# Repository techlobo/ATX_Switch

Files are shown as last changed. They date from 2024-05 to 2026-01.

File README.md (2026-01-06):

# ATX Switch

## Control ATX capability of multiple systems from PiKVM host

An extension unit to a [PiKVM](https://github.com/pikvm/pikvm) based controller that enables the WebUI based ATX controls (PWR button; Reset button; HDD LED and PWR LED) to be switched between the physical ATX headers, and their associated case controls, on different PC / Server motherboards.

Supports the control of multiple ATX-enabled endpoint devices, in conjunction with a KVM switch, from a single PiKVM unit.

>[!NOTE]
>An interface adaptor has now been produced that enables PiKVM v3 and v4 Plus devices to be connected to, and manage, an ATX Switch environment

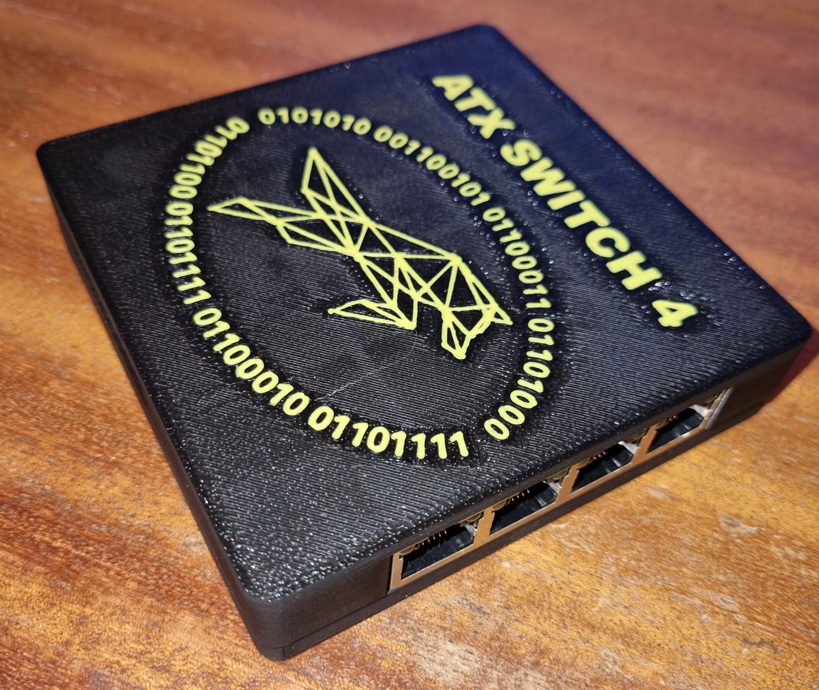
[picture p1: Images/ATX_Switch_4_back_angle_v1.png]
ATX Switch 4 picture
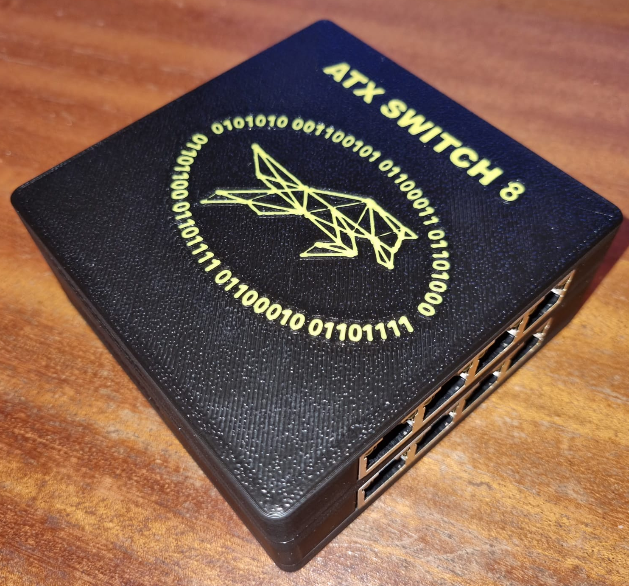
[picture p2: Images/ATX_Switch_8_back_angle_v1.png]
ATX Switch 8 picture
|  |  |
| --- | --- |

## Features

- $\color{green}{\textsf{Low cost}}$ / **<u>self-assembly</u>**

- 4-port and 8-port units can be built
  - [Board / case designs available](https://github.com/techlobo/ATX_Switch/tree/main/ATX_Switches)
  
- I2C addressable (user selectable between 0x20 – 0x27)

- Daisy chainable (theoretically up to 8 units / 64 ports)

- Fully isolated

- Compatible with PiKVM assigned ATX GPIO pins

- Port selection controls available in WebUI (configurable via override.yaml)

- ATX operations use standard PiKVM WebUI interface

- Potential for ATX operations to be performed via I2C rather than GPIO (**not implemented yet**)

- Compatible with existing PiKVM based ATX adapter boards that are installed inside managed PC / workstation / server
  - Design available to build own [affordable ATX adapter board](https://github.com/techlobo/ATX_Switch/tree/main/ATX_Adapter_board)
  
- ATX Switch input port not compatible with existing v3 / v4 PiKVM hardware designs of ATX port due to requirement for providing control and power lines. Therefore cannot directly connect commercial PiKVM unit to ATX Switch. Two build approaches available:
  - [Low-cost DIY design](https://github.com/techlobo/ATX_Switch/tree/main/DIY_PiKVM) available based on v3 Box build (**self-assembly**)
  
    - 👀 Limited to 1080P @50Hz 👀
  
      <p align="center">
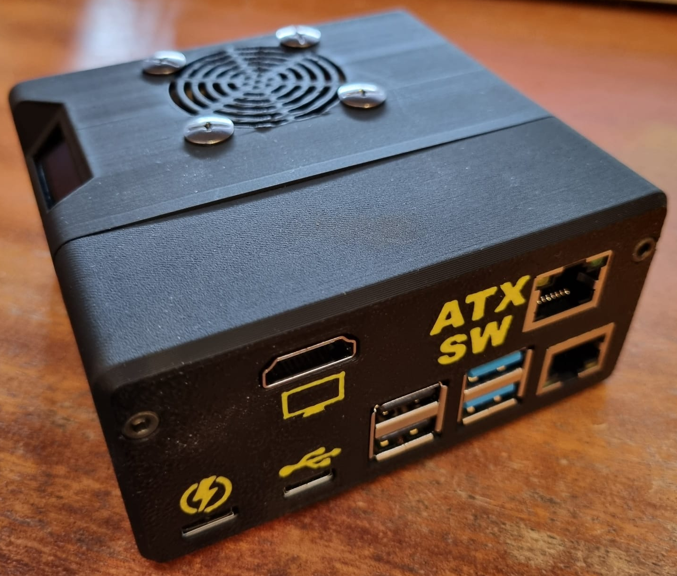
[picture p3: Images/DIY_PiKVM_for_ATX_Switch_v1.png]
DIY PiKVM for ATX Switch operation
      
      </p>

  - $\color{green}{\textsf{New addition}}$ - [ATX Switch Interface adaptor](./ATX_Switch_Interface_adaptor/README.md) (**self assembly**) enables connection between v2 / v3 / v4+ devices and ATX Switch environment.
  
    <p align="center">
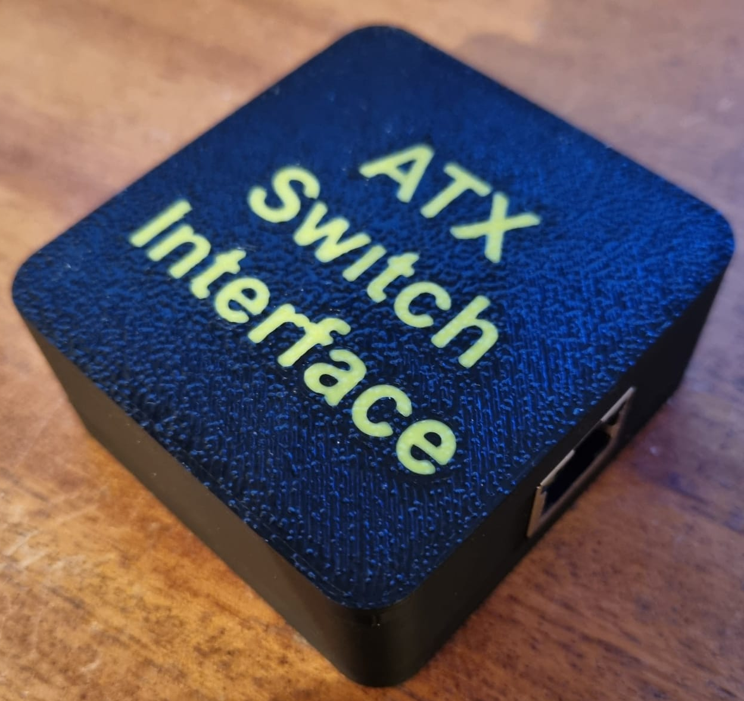
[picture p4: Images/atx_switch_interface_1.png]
ATX Switch Interface adaptor
    
    </p>
  
  - $\color{green}{\textsf{Further addition}}$ - [Low cost DIY v2 Design](./DIY_PiKVM_v2/README.md) (**self assembly**) - modified version of DIY design above to provide standard ATX functionality as per v3 / v4 PiKVM units
  
    <p align="center">
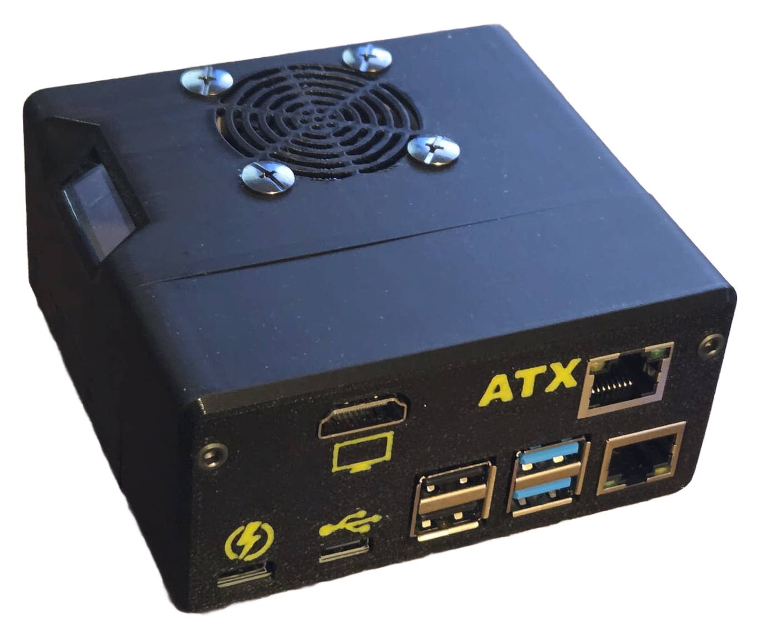
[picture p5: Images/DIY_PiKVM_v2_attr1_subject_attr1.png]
DIY PiKVM for standard ATX operation
    
    </p>

## Typical deployments

##### $\color{purple}{\textsf{DIY PiKVM - most cost effective for home lab environments}}$

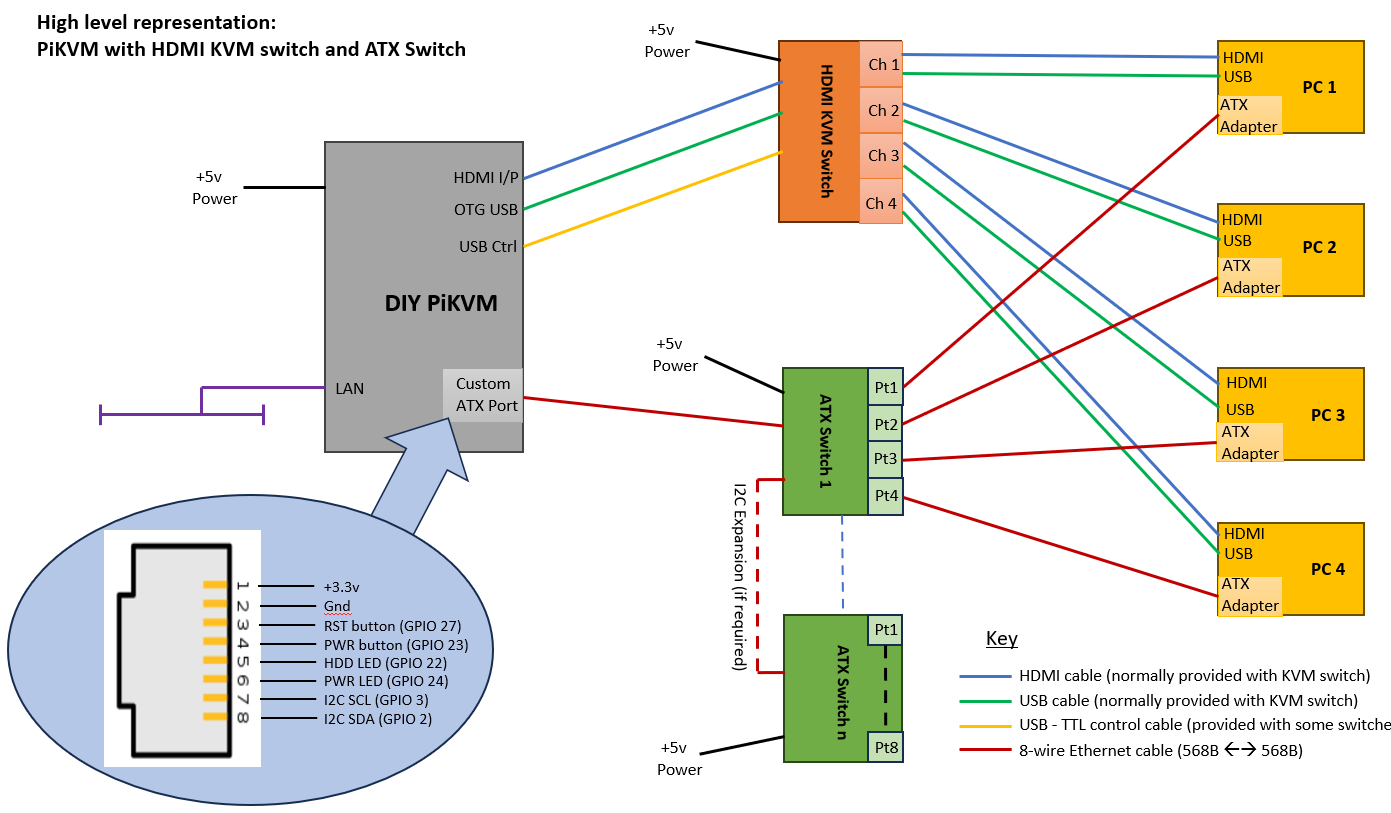
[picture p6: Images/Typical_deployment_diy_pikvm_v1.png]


##### $\color{purple}{\textsf{Commercial PiKVM environments}}$

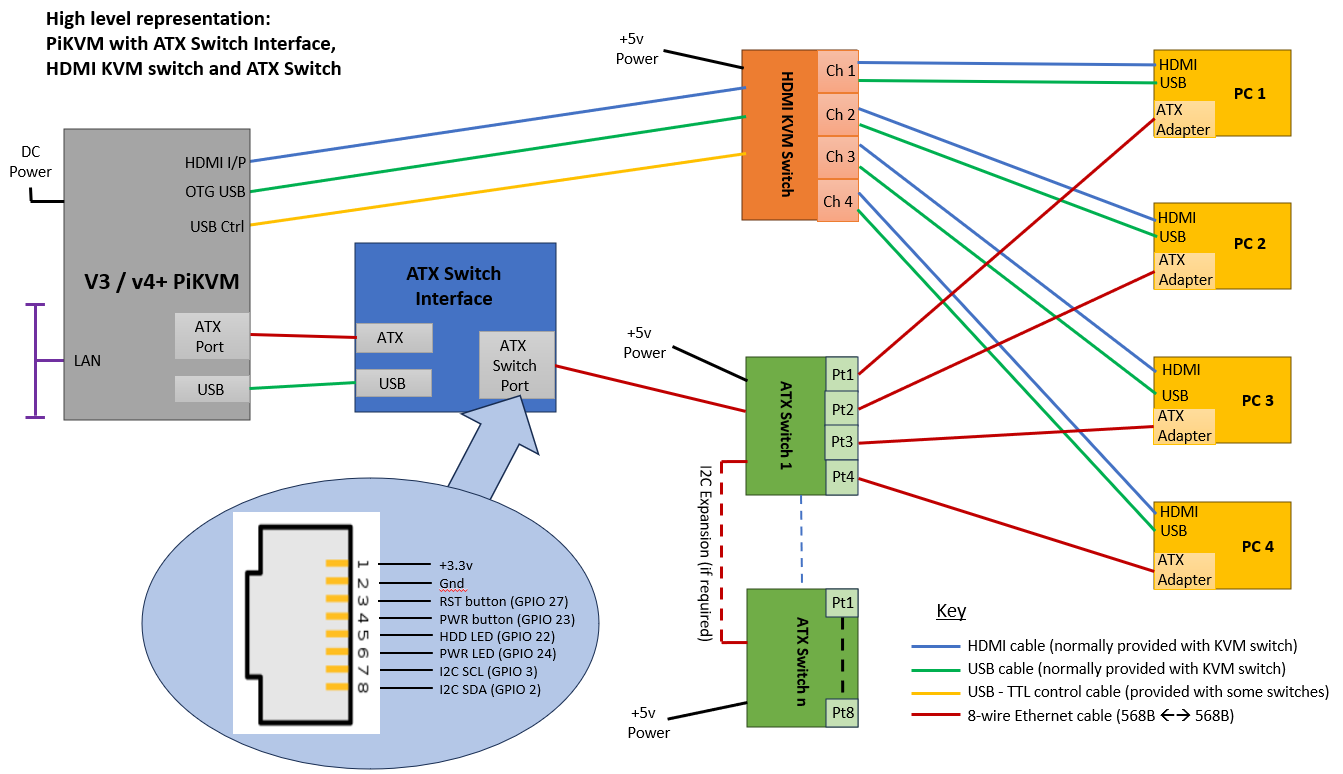
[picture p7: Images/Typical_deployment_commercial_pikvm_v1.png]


## Background

As PiKVM usage was developing, more users were wanting to extend its functionality to support multiple end-devices from a single PiKVM controller. This led to experimentation regarding the use of HDMI KVM switches to enable multiplexing of input / output streams between the devices.

This work by the community has led to a greater understanding of which HDMI KVM switches work best with PiKVM, and how to configure them. Some of this information has been [documented](https://docs.pikvm.org/multiport/) on the PiKVM site, whilst other information is available in the PiKVM discord server and various articles online.

However these approaches did not address one of the key capabilities of the PiKVM when used in a multi-device scenario - the ability to switch on / off the remote device, and to a lesser extent a visual confirmation of its power and HDD status.

I had just restarted an interest in hobby electronics and wanted an affordable solution for managing my home server environment,  so decided that this would be a good first project. 

I originally considered the construction of discrete '*intelligent*' controllers, using ESP32 (or similar) MCU's connected to the PiKVM via a bus based approach (e.g. Modbus, CANbus, MQTT). It was interesting testing these approaches out whilst determining how to: **design / build them** (e.g. component selection, PCB design, enclosure design); **deploy them** (e.g. where / how to install them, how to power them, how to communicate with them); and **manage them** (e.g. configuration / debug / maintenance). 

I learnt a lot during this exercise, but finally concluded that the approaches I was considering were more complicated than necessary, and that a simpler / more robust / cheaper solution could be produced just using devices based on discrete components connected directly to the PiKVM controller - hence the ATX Switches!

## Operation

When correctly configured, operation of the ATX Switch(es) is undertaken within the PiKVM WebUI. The means of this operation depends on how the system has been set up (see installation instructions).

### Managed device selection

This is performed within the **Source** menu option by either:

- activating the associated ATX(x) button, OR
- activating the associated Input(x) button if HDMI KVM switch integration has been performed. 

The selected port on the ATX Switch being indicated on the associated menu LED.

<p align="center">
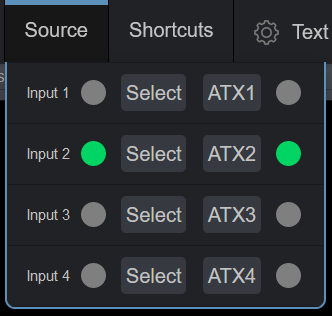
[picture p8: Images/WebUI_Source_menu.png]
DIY PiKVM 3D printed case

</p>

The video below gives a brief demonstration of the above activations, initially by using the ATXn selector buttons to switch between the managed devices - the associated LED (within the Source menu) changing to confirm selection complete. You can also see that the ATX menu LED icons change to indicate the status of the selected device (with ATX1 being powered off). The second part of the video shows selection of the target device using the Source menu 'Select' buttons which are mapped to the attached HDMI KVM switch. Observe how the selection of the KVM target causes the ATX Switch to be moved to the associated ATX interface.

<video src="./Images/PiKVM_ATX_op1.mp4"></video>

https://github.com/techlobo/ATX_Switch/assets/95144096/9a94704d-ef98-44f7-9990-24d5c0a44960

### ATX Functionality (via GPIO)

This is performed via the ATX menu in the WebUI, with the Power LED and HDD LED status for the selected device being indicated in the menu bar (*Note - this is all standard PiKVM functionality when GPIO controls are being used*).

The video below again shows the target device being selected from the Source Select buttons, but in this case the target device (4) is powered down. The completion of the LED representations in the Source menu shows that the 4th HDMI KVM port was selected alongside the ATX Switch 4th port. It can also be seen from the ATX menu that the status indications for Power and HDD are blank. On using the standard PiKVM ATX functionality to power on the target device it can be seen that the activity indicators start to operate, and the boot process is observed.

<video src="./Images/PiKVM_ATX_op2.mp4"></video>

https://github.com/techlobo/ATX_Switch/assets/95144096/6d380cd4-e1c7-4d97-97c2-12fe709a398f

The presentation of the Source menu is down to personal preference (as defined in the override.yaml file). It is not necessary to provide the ATX selection buttons, or indeed the selected ATX LEDs, if you are happy with just using one set of selection buttons, and having one set of 'selected' LEDs. Personally I prefer to show both sets of LEDs.

## Rough Costs

My approximate material costs for the final pieces of this project (not including IC sockets) were as shown below, on a pro-rata basis:

| Item | Rough cost - own case (£) | Rough cost - buy case (£) |
| --- | :---: | :---: |
| ATX Adapter board | $\color{green}{\textsf{3.00}}$  | N/A |
| ATX Switch 4 | $\color{green}{\textsf{19.00}}$ | 39.00 |
| ATX Switch 8 | $\color{green}{\textsf{27.00}}$ | 51.00 |
| DIY PiKVM (ATX-SW) | $\color{green}{\textsf{97.70}}$ | 119.70 |
| ATX Switch Interface | $\color{green}{\textsf{7.50}}$  | 26.00 |
| DIY PiKVM v2 (ATX only) | $\color{green}{\textsf{98.20}}$ | 118.20 |

>[!NOTE]
>The costs are based on the use of optocouplers for the ATX Switches. If SSRs were to be used then add at least an additional £10 to the cost of a 4-port, and £20 to an 8-port device.
>
>In the case of the DIY PiKVM v2 this has been costed using the KAQY214 SSR's to more closely match standard PiKVM spec.

A bit more detail is provided [here](./Rough_costs/README.md).

Some further savings can be made (e.g. cheaper fan, no fan at all, use of dupont cable rather than motherboard switch extender,....) but these are what I went with.

## Credits

None of the above would work without the amazing efforts of the developers of [PiKVM](https://pikvm.org/), and their support of the [Open Source community](https://github.com/pikvm). Hats off to them!

## Summary & Disclaimer

This is a synopsis of my adventures in this area while setting up management on my home lab environment. It works for me, but there are no guarantees it will for you. I've documented this primarily for my own benefit, including getting some idea of how Github and Markdown works. However, if you want to try something similar then please feel free to use any (*or none*) of the above material - $\color{red}{\textsf{at your own risk...!}}$

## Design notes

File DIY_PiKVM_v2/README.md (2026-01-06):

# DIY PiKVM v2 (single ATX) Section

<p align="center">
DIY PiKVM v2 3D printed case
</p>

The *DIY PiKVM v2* consists of:

## Hardware

- [3D printed case](./Case/README.md)
- Pi4 (suitable for PiKVM)
- [Power splitter](https://www.tindie.com/products/8086net/usb-cpwr-splitter/) from 8086.com
  - Barrel jack version not required, although will fit.

- [Angled USB-C cable](https://www.startech.com/en-gb/cables/r2ccr-15c-usb-cable) connecting Power splitter to Pi4 USC-C power supply port
  - Other cables / adaptors can potentially be used but I found this item to be best for the available space / bend.

- [C790](https://geekworm.com/products/c790) to provide HDMI-CSI2 video capture 
  - FPC 15-pin cable should also be supplied 
  - (audio if required using supplied I2S cable)

- [ATX connector](./ATX_connector_board_for_Pi/README.md) (RJ45 configured as per standard PiKVM ATX socket)
- [0.91 inch OLED screen](https://www.aliexpress.com/item/1005005281308478.html) (typically white / yellow / blue)
  - 4-pin female-to-female dupont ribbon cable

- 4x 2mm silicone cushion mat self adhesive rubber feet
- **Optional** - 40x40x10 fan (preferably PWM). Few types tested:
  - [Noctua NF-A4x10 5V PWM](https://noctua.at/en/nf-a4x10-pwm)
  - [Pi5 PWM fan](https://thepihut.com/products/4010-cooler-black-fan-for-raspberry-pi-5?variant=42684803907779)
  - [GeeekPi PWM fan](https://www.amazon.co.uk/GeeekPi-Raspberry-Adjustable-40x40x10mm-Radiator/dp/B092ZF995F?th=1)
  - There are others, but not tested.

The case construction allows for mainly tool-less assembly, however the following bolts / connectors **are** used in the build of the unit:

- 2x M3 35mm bolts for connecting the front and back of the case together.
  - I used [black hex socket head bolts](https://www.aliexpress.com/item/1005005832717344.html) (to match in with the black PLA) together with [M3(OD4.5) 6mm heat inserts](https://www.aliexpress.com/item/1005006042691803.html) in the case back to provide a good fit that can be opened / closed easily. The use of heat inserts is not compulsory but the inner diameter of the mounting hole on the back case will probably need to be adjusted if M3 screws (or bolts) are to be used on their own.
- 4x M3 15mm bolts / nuts to fasten the fan into place
  - I used [black D4(M3) screw book binding post screws](https://www.aliexpress.com/item/32789781458.html) together with rubber washers to provide a good looking finish with the Noctua NF-A4x10 5V PWM fan.
- **Optional** - depending on preference, an M2.5 brass standoff spacer (18mm) can be used in conjunction with 2x M2.5 6mm low flat screws to fasten the ATX Switch connector board to the Raspberry Pi4. This is not essential as the case construction will hold the components together, but may provide rigidity during assembly.

Hardware assembly and software is basically the same as for [DIY_PiKVM](../DIY_PiKVM/README.md), although the ATX Switch scripts are not required if only using this as a 1:1 v2 ipKVM device. The ATX Switch scripts do need to be installed if intending to use this device in conjunction with the [ATX Switch Interface adaptor](../ATX_Switch_Interface_adaptor/README.md) (see relevant installation notes).

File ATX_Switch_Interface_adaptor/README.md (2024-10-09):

# ATX Switch Interface

## Design Criteria

After producing the ATX Switch / DIY PiKVM combination for my home environment, I revisited whether it would be possible to use the ATX Switch with one of the standard PiKVM's.

The main interface to the ATX Switch environment is the relevant GPIO pins, and I2C. However the PiKVM devices were fixed units - with no expansion capability unless you used existing ports, or 'hacked' the units (which most people won't want to do!).

Therefore it was necessary to determine if the provided ports could be utilised / re-purposed.

The standard ATX port on the PiKVM has a fixed pinout, but the relevant GPIO pins could be mapped externally to the configuration used by the ATX Switch.

Which left the need to provide an I2C interface.

The only other ports available for use on the PiKVM were the USB ports, so it was decided to look at providing a USB<-->I2C interface.

A number of USB<-->I2C adaptors were reviewed based on functionality / availability / support / cost .....

It was determined that the CP2112 HID USB to SMBus / I2C Bridge had kernel support within Arch Linux[^1], and was available in a relatively inexpensive 'debug board' package:

 <p align="center">
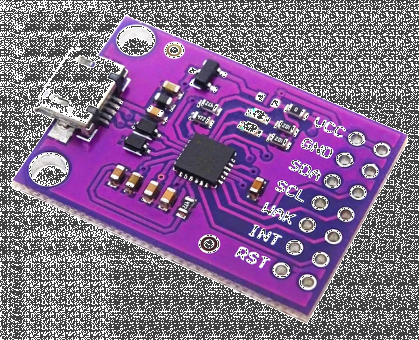
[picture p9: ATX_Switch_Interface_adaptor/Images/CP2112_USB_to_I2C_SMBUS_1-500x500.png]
CP2112 Debug board
    
    </p>

This board was tested in the ATX Switch environment and supported the required functionality, with minimal code changes.

A simple board was then constructed incorporating the CP2112 board and a pair of RJ45 connectors, to provide the interface between the PiKVM and ATX Switch.

 <p align="center">
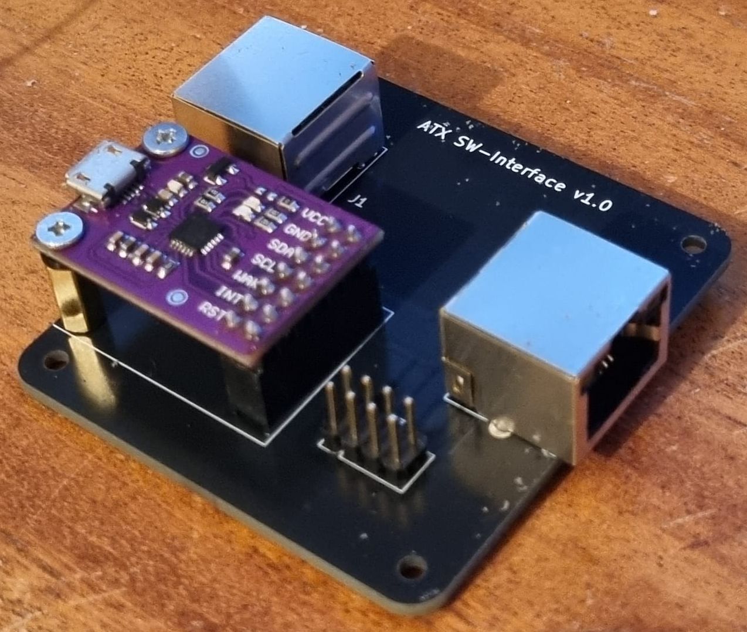
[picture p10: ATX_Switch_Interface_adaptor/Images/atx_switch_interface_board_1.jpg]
ATX Switch Interface board
    
    </p>

>[!NOTE]
>
>The CP2112 board also supports GPIO expansion, although this capability was not specifically required for the purpose of this interface adaptor. It may be possible however for this approach to be used to control the ATX functionality (via the ATX Switch) by remapping GPIO pins in the PiKVM code. 
>
>Accordingly four of the CP2112 board GPIO pins (3, 4, 5, 6) have been configured so that they can be jumpered to ATX Switch functionality (RSTB, PWRB, HDDL, PWRL) if desired[^2].
>
>$\color{red}{\textsf{THIS FUNCTIONALITY HAS NOT BEEN TESTED!!!}}$

## Required Parts

- [3D printed case](./Case/README.md)
- [ATX Switch Interface board](./Board/README.md)
- CP2112 debug board
- 4x M2.5x10 countersunk bolts[^3] 
- USB-A to micro-USB cable
- 2x 8-wire Ethernet cables

## Installation

Connect the ATX Switch Interface to the PiKVM (as per the overview diagram in the introduction)

- 8-wire Ethernet cable between the ATX port on the PiKVM and the ATX port on the Interface
- USB cable between spare port on the PiKVM and the micro-USB port on the Interface

Connect ATX Switch Interface to the ATX Switch using an 8-wire Ethernet cable.

Start the PiKVM and determine the BUS ID of the CP2112 controller in the ATX Switch Interface by running the command:  **i2cdetect -l**

The output should be similar to:

 <p align="center">
    i2cdetect output
    </p>
In the above we can see that the CP2112 controller is on bus 23

Verify that the CP2112 I2C controller is working and can see the attached ATX Switch(es) by using the command :  **i2cdetect -r -y 23**  (substitute the bus ID determined above for the last value, if necessary)

>[!NOTE]
>
>The CP2112 module is unable to use the I2C quick write capability, so the **-r** parameter must be used to get proper output.

The output should be similar to:

 <p align="center">
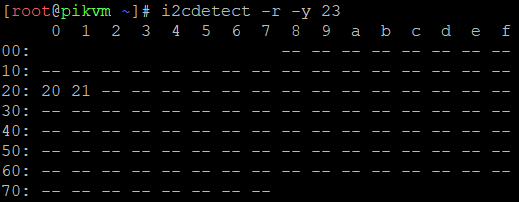
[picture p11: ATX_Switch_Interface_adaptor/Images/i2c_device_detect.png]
Devices detected on I2C channel
    
    </p>
Here we can see that there are 2x ATX Switches configured at addresses 0x20 and 0x21

Update the value in the 'i2c_bus_id' field in the ATX Switch environment configuration file (**atx_switch_initialisation.yaml**) to reflect the bus ID determined[^4]

Configure the rest of the ATX Switch environment within the PiKVM (using the approach defined in the DIY PiKVM [Scripts](../DIY_PiKVM/Scripts/README.md) area).

>[!NOTE]
>
>Ensure that the PiKVM kernel has been updated to include CP2112 support by running **pikvm-update**

###### Footnotes

[^1]: Initially it was determined that the PiKVM kernel had not been built with CP2112 support included, but Max kindly reconfigured the kernel to re-instate support - my thanks for this.

[^2]: If this approach were to be used then make sure that nothing is connected to the ATX port connector (RJ45) on the interface unit - as the ATX port on the PiKVM will still be physically connected to the assigned GPIO pins on the Raspberry Pi.

[^3]: Can use screws but will need to reduce size of affixing hole in case top

[^4]: The original ATX Switch environment scripts had the 'standard' Pi4 internal bus ID (=1) hardcoded in two locations. These could be manually changed quite easily, but it was decided to include the bus_id as a configurable item and the code was changed to use this value from the configuration file.

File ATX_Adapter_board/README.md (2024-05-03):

##### ATX breakout adapter for insertion inside case of managed device (PC / Server).

<p align="center">
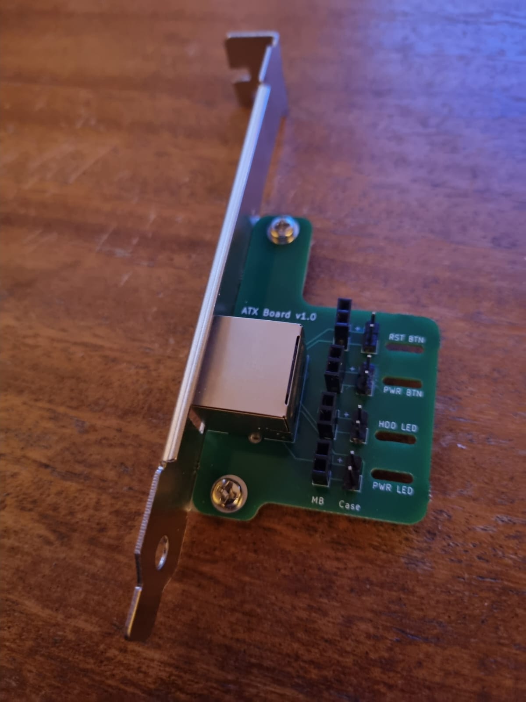
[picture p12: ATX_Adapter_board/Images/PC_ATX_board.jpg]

</p>

Compatible with pinout of [PiKVM ATX control board](https://docs.pikvm.org/atx_board/#pinout) enabling connection to managed devices ATX header, and its case controls (where appropriate).

The board is **self-assembly** and provides two banks of 4x 2-pin connectors for motherboard (MB) and case connectivity respectively. The connector rows are labelled with the ATX header / case connector that they relate to - Reset button (RST_BTN); Power button (PWR_BTN); Hard drive activity LED (HDD_LED) and Power LED (PWR_LED).

In reality the MB and Case banks are 1:1 connected so can be connected to either ATX header or case cables provided that compatible 2-pin connectors are installed. However to reduce the risk of mix-up during installation my preferred approach has been to use:

- Male connectors to support case connectivity (if this is to be used), as case cables are normally provided with female plugs on their ends.

- Female connectors to support ATX header connectivity.

  - Note - this requires the use of Male-Female Dupont ribbon cable (or similar) to allow connection to the male headers on the motherboard.

  - My preference has been to use a PC motherboard switch extender for this - mainly as the ends are labelled, which reduces installation risk. However I also think they look better than multicoloured ribbon cable. They are more expensive though!

    <p align="center">
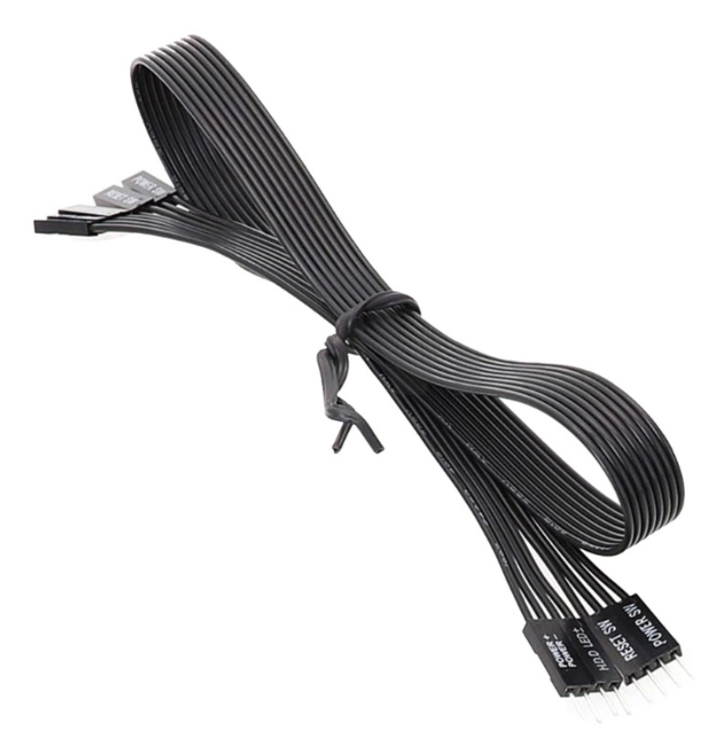
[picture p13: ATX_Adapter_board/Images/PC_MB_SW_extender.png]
    
    </p>

The board has been designed to work with the metal brackets for the single port Intel X540-T1 NIC which are available in both full height and low profile variants:

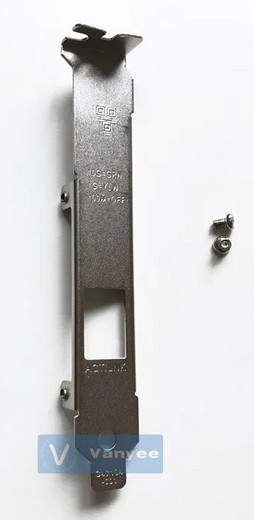
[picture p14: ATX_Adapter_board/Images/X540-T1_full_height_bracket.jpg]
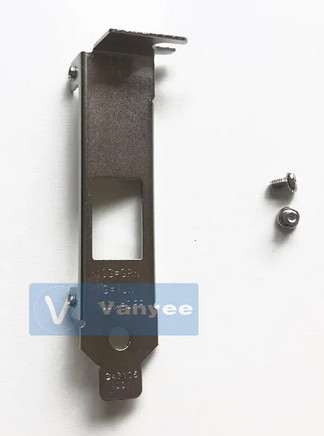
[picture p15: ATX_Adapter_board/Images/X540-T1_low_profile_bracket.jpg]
|  |  |
| --- | --- |

These are available from a number of vendors (which keep changing).

At the time of writing the cheapest available was from a vendor on AliExpress:

- [Full Height](https://www.aliexpress.us/item/3256804856153513.html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)
- [Low Profile](https://www.aliexpress.us/item/3256805210264567.html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)

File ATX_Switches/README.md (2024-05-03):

# ATX Switches (4 & 8 port)

## Design criteria

The ATX switches were designed with the following criteria in mind:

- Expandable - to support varying numbers of managed devices
- Isolation - to prevent damage between managed devices, and DIY PiKVM controller
- PiKVM compatibility - in so far as possible
- Simplicity
- Ease of construction / testing - assuming basic soldering skills
- Substitution - using pin compatible components. e.g. the user can decide whether to use SSRs or optocouplers (which are a fair bit cheaper) to provide the interface to the managed devices.
- Education / interest for me - tools / processes / techniques / vendors / components / etc.

As mentioned previously I originally had considered creating a solution based on a distributed MCU based architecture, but while the experimentation with this was interesting I eventually decided that it was more complex than was necessary for my purpose. I therefore decided to create a solution based on discrete components, with the communication between the PiKVM environment and the ATX Switch(es) being restricted to I2C and the relevant GPIO pins used for ATX operations.

> [!NOTE]
> At the time I started this exercise the only PiKVM available was the v3 (HAT and pre-built unit), with the main restriction being that it only supported 1080p @50Hz - and the majority of this functionality could be enabled via a v2 (DIY) approach.
> 
> Since then the v4 has been released with support for 1080p @60Hz, along with other features, which is not easily replicable with a DIY build (an approach that **is not** supported by the PiKVM team). So it is possible that a distributed (bus based) approach may have worked better in the long term...? However I still prefer the simplicity of the approach taken - perhaps a future expansion may be to produce a '*networked*' controller that can communicate between the PiKVM and the ATX Switch environment. OR maybe the PiKVM team will make the ATX port configurable...?     Anyway I digress.

The majority of HDMI KVM's that were being used within the community were 4-port or 8-port, as these were large enough for the bulk of home environments. Therefore I opted to create a 4-port main board that could be expanded to 8-ports by the addition of a daughter board - thus saving cost on some of the common components: Pi4 isolation (I2C and GPIO); I2C expander; power supply; Address selection switch; and various connectors. 

| Main Board | Daughter board |
| --- | --- |
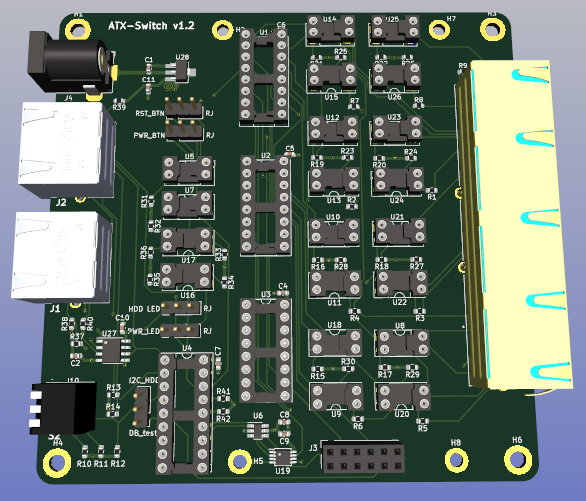
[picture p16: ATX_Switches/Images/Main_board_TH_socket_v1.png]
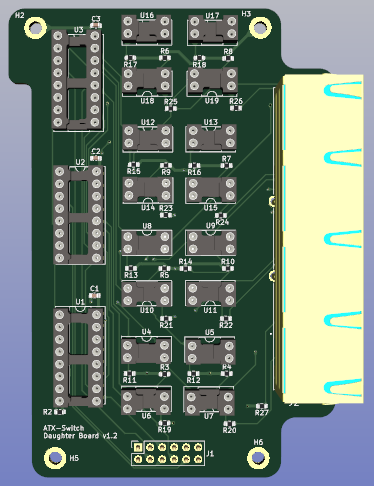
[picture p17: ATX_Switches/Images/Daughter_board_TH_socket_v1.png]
|  |  |

However, being aware of larger HDMI KVM switches (and the ability to daisy-chain some HDMI KVM switches), I decided to design the ATX Switch to also allow expansion of the I2C and GPIO channels from the Pi4. 

An MCP23008 I2C I/O expander provides three address pins enabling 8x ATX Switches to be daisy-chained, giving a theoretical managed device capacity between 32 - 64 (**I've never tested to this capacity!**).

Signal isolation is provided on both the DIY PiKVM and managed device sides of the ATX Switch.

An RJ45 extender port (nearest to the power socket) enables the I2C and GPIO signals from the DIY PiKVM to be forwarded to the downstream ATX Switches in a daisy chained environment.

The pinout for the connection between the DIY PiKVM and the ATX Switch is custom (due to the signals required)[^1], however it does use the same GPIO pins as used within the PiKVM thus ensuring that ATX operations from within the WebUI are the same. Also the pinout used for the ports that connect to the managed devices is the same as that used by the PiKVM for its [ATX port](https://docs.pikvm.org/atx_board/#pinout).

Further criteria are covered in the [Main board](./Boards/Main_board/README.md) section.

## Required Parts

- [3D printed case](./Cases/README.md)
  - 4-port or 8-port variant
- [Main board](./Boards/Main_board/README.md) (4-port)
  - plus [Daughter board](./Boards/Daughter_board/README.md) (for 8-port)
- Power supply - 5V, 2.1mm barrel jack
- 4x M3 countersunk bolts[^2] (14mm for 4-port case, 35mm for 8-port case)
  
- 4x 10x2mm self adhesive rubber feet

## Installation / Operation

As designed, installation / operation of the ATX switch is straightforward, with most of the configuration complexity happening on the DIY PiKVM controller.

###### Basic PiKVM GPIO ATX operation

1. Set the internal jumpers on the [main board](./Boards/Main_board/README.md) before sealing the case.
   1. Currently, as I2C ATX operations are not supported yet, all jumpers (RST_BTN; PWR_BTN; HDD_LED; PWR_LED) should be set to 'RJ'.
   2. Set the remaining jumper to DB_test - this is a software configurable item which may not be used, but if I2C operations are not being used then the I2C_HDD functionality is not required.
2. Set the address of the ATX Switch using the address selection switch levers.
   1. If only one ATX Switch is to be deployed it is recommended that this be left at the default 0x20, however it can be changed provided that the matching address is configured in the **atx_switch_initialisation.yaml** file on the DIY PiKVM
3. Connect the output ports from the ATX Switch to the [ATX Adapter board](../ATX_Adapter_board/README.md) on the corresponding managed device using an 8-wire Ethernet cable[^3].
4. Connect the DIY PiKVM to the ATX Switch (RJ45 port nearest the address switch) via an 8-wire Ethernet cable[^3].
5. Plug in the 5V power supply.
   1. The green LED on the RJ45 port should illuminate.
6. When the DIY PiKVM is powered on / booted the amber LED on the RJ45 port should illuminate
   1. There is an option within the ATX Switch software (on the DIY PiKVM) to run a port test at initialisation. If this is configured then during the boot process the ATX Switch should cycle through port selection, which will be indicated by the port green LEDs switching on and off one at a time.

###### Extended (daisy-chain) operation

1. Perform the above steps for each switch, but in the case of the extra switches ensure that the address is set to a unique value (in the range 0x20 - 0x27).
2. Connect the switches together using 8-wire Ethernet cable(s) [^3]
   1. When power is applied then the downstream ATX Switches should have both the green and amber LEDs illuminated (on the DIY PiKVM RJ45 connector). This indicates that there is power to the ATX Switch (green), and that it is connected to the upstream switch (amber).
   2. The amber LED on the first ATX Switch in the chain will only be illuminated when the DIY PiKVM is powered-up / booted.

###### Custom I2C operation

The ATX Switch **can** support ATX operations using I2C commands, but not from the PiKVM WebUI environment currently. These need to be performed using Linux commands such as **i2cset / i2cget**.

In order to support this mode of operation the above steps still need to be performed but the internal jumpers need to be set to support I2C operations. i.e. moved away from the 'RJ' side to the other side.

If you want to get the HDD_LED status via I2C it is also necessary to switch the jumper from DB_test to I2C_HDD. This will lose the ability to test for presence of a daughter board, but this is less of an issue once the environment is operational.

The use of I2C for ATX operations also needs to be configured in the **atx_switch_initialisation.yaml** file on the DIY PiKVM (set **atx_ops** to **i2c**).

>[!NOTE]
>It is possible to have a mix of ATX Switches supporting standard GPIO and I2C operations in a daisy-chain (only one type per switch) - however this is an advanced use case.

###### Footnotes

[^1]: As the pinout of the PiKVM port is not configurable unfortunately
[^2]: Can use screws but will need to reduce size of affixing hole in case top.

[^3]: All Ethernet cables are to be straight (568B <--> 568B), not cross-over. All cable lengths should be kept to the minimum length possible to reduce likelihood of signal / power degradation.

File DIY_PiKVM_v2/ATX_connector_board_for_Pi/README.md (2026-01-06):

## ATX Connector board

Dip Variant

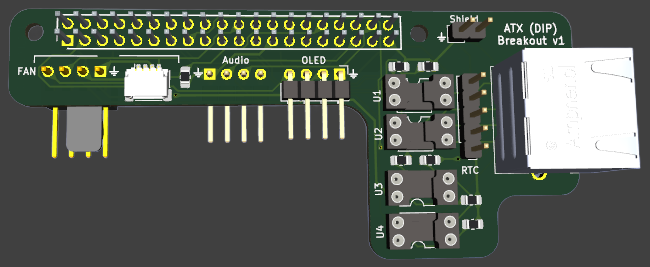
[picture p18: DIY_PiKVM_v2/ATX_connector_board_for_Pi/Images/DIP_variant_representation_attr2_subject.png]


SMD Variant

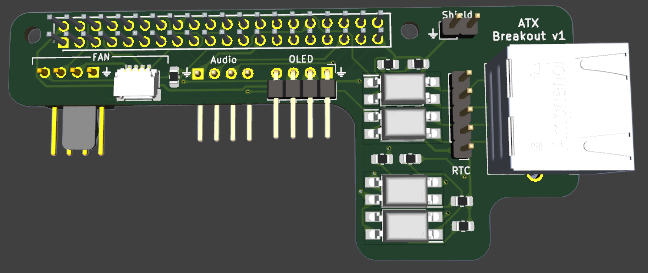
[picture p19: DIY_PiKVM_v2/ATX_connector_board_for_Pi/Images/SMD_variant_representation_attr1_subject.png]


Basically the same board with different choice of components / construction approach. In the case of the DIP variation you can use sockets (which I have a preference for) and decide which components to use (opto-couplers / SSR's) during installation. Although you can also dispense with the sockets and solder DIP components directly to PCB.

The board maps the following GPIO pins of the expansion header to the opto-isolators / SSR's to enable normal (single) ATX operation from a PiKVM enabled Pi4.

|  Function  | Pi4 GPIO pin (physical) | Pi4 (Logical) |
| :---: | :---: | :---: |
| RST button | 13 | GPIO 27 |
| PWR button | 16 | GPIO 23 |
|  HDD LED | 15 | GPIO 22 |
|  PWR LED | 18 | GPIO 24 |

The RJ45 header is mapped directly to the pinout used by PiKVM v3 / v4 units as defined in the ATXRJ-45 pinout at https://docs.pikvm.org/atx_board/

The board is  **self-assembly**, hosts the required opto-isolators / SSR's, and includes connectors for a [mini RTC (Real Time Clock) module](https://www.aliexpress.com/item/32828162429.html) and the various elements included in the case:

- Pi4 GPIO expansion header
  - The design uses a [2x20 three layer heightened 2.54mm GPIO header](https://www.aliexpress.com/item/1005005366790021.html) to provide clearance to Pi4 USB3 / Ethernet connectors, and match up with the mounting slots in the case front.

- OLED header
- Fan (PWM enabled) header
  - [KF2510 3+1P male connector](https://www.aliexpress.com/item/1005002905132620.html) provided for keyed operation with Noctua NF-A4x10 5V PWM fan. Can also be used with 2-4pin fans using Dupont 2.54mm female connectors.
  - [4-pin SH1.0 connector](https://www.aliexpress.com/item/4001225684969.html) for use with suitable fans (e.g. new Pi5 40x40x10 PWM fan)
  - Note1 - PWM pin is grounded via 4.7Kohm resistor to enable fan to be stopped when PiKVM is halted.
  - Note2 - Tacho (RPM) pin is available but doesn't always seem to work reliably with PiKVM software (sometimes reports that fan is not working). I didn't investigate this exhaustively as PWM operation worked fine, so just ended up not configuring the 'hall_pin' in /etc/kvmd/fan.ini

- Audio header (from C790 HDMI-to-CSI adapter)

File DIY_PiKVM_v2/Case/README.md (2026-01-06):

#### 3D printed Case for DIY PiKVM v2 that supports single ATX operation

<p align="center">
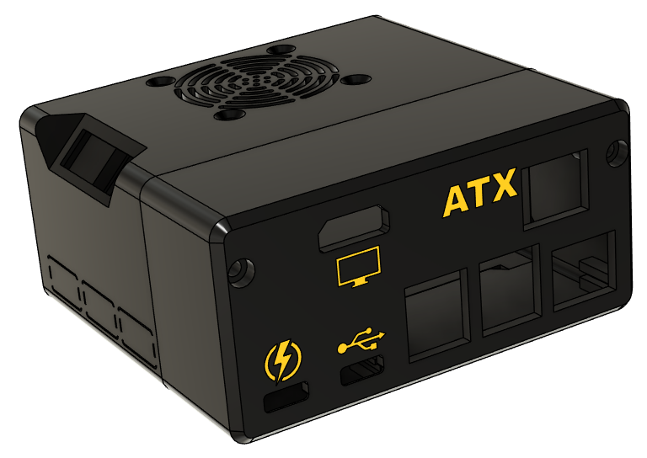
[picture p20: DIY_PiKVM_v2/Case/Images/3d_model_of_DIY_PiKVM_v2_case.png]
DIY PiKVM v2 3D printed case

</p>

Printed in PLA the case supports:

- Pi4
- Power splitter from 8086.com
- C790 to provide HDMI-CSI video capture (and audio if required)
- ATX connector (RJ45 configured as per standard PiKVM ATX port)
- 40x40x10 fan

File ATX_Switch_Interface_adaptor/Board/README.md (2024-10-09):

# ATX Switch Interface board

 <p align="center">
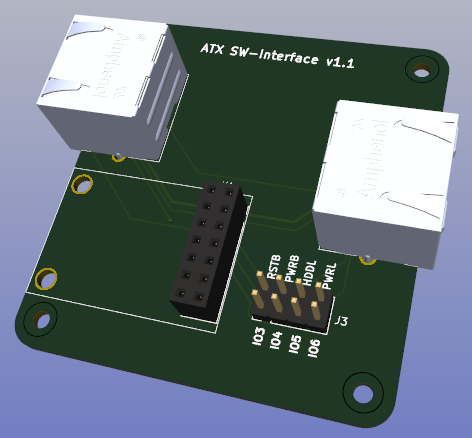
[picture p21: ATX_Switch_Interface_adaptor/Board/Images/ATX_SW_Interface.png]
ATX Switch Interface board
    
    </p>

Basically this simple board just takes the I2C outputs and power from the CP2112 debug board (connected to PiKVM via USB), together with the active GPIO pins from the ATX port, and maps these to the pin configuration used by the ATX Switch.

Consists of:

- PCB
- 2x RJ45 connectors
- 1x 7x2row female (socket) connector - 2.54mm
- 1x 4x2row male (pin) connector - 2.54mm
- CP2112 debug board (with 7x2row pin connector soldered to underside)
- 2x M2.5 11mm brass standoffs
- 4x M2.5x5mm flat head bolts

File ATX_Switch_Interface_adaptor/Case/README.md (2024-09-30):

# ATX Switch Interface case

<video src="./Images/ATX_SW_Interface_v1.mp4"></video>

https://github.com/user-attachments/assets/1a655d50-f39f-413e-b5ea-170363b08b48

Consists of:

- Printed in PLA
- Uses  [M2.5 (OD3.5) 6mm heat inserts](https://www.aliexpress.com/item/1005004975376499.html) within the support pillars to allow for repeated opening / closing. 

Case parts are fastened together with 4x 12mm countersunk black M2.5 bolts.

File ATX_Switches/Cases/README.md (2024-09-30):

# ATX Switch Cases

3D printed case designs are available for both 4-port and 8-port ATX Switches

## 4-port - (ATX SWITCH 4)

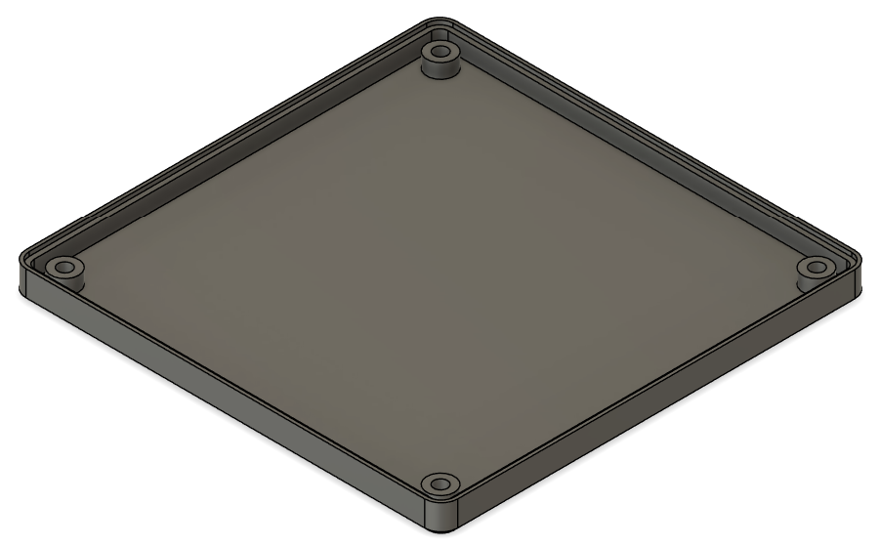
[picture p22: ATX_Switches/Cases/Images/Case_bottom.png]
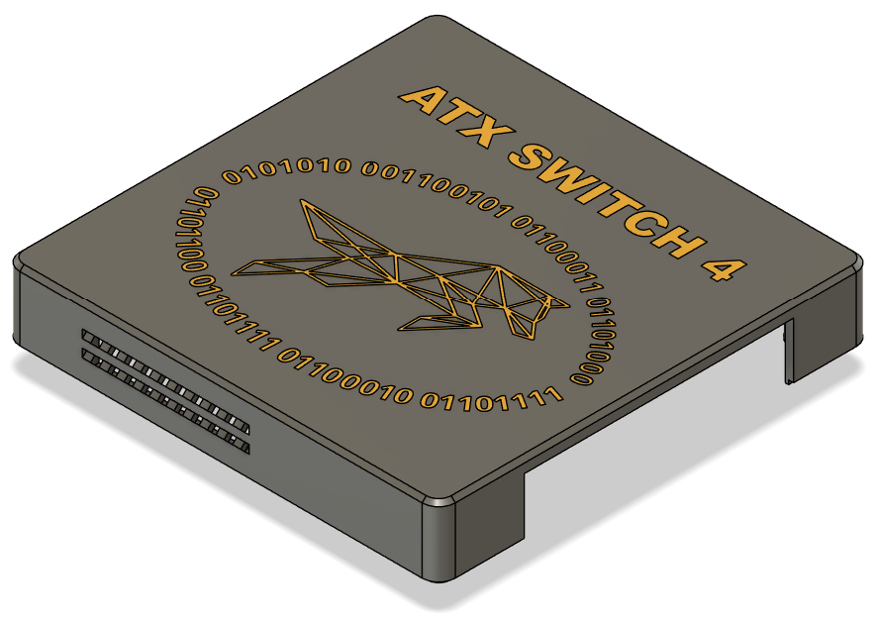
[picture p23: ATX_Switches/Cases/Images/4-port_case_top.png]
|  |  |
| --- | --- |
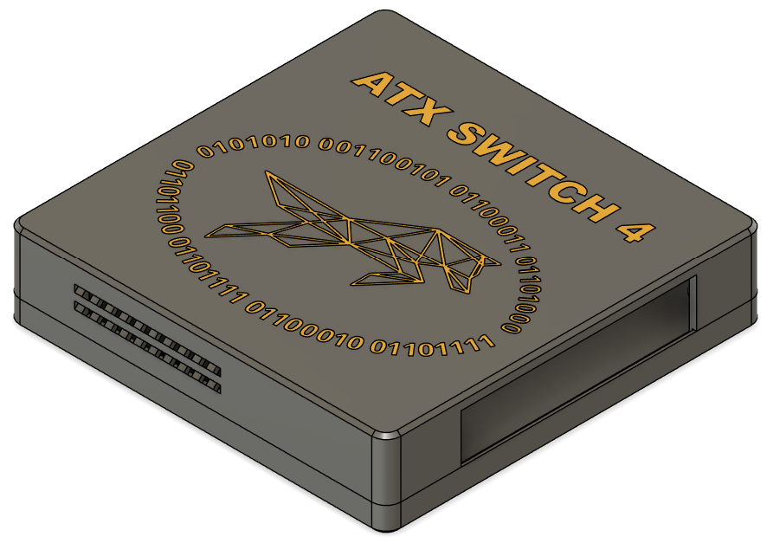
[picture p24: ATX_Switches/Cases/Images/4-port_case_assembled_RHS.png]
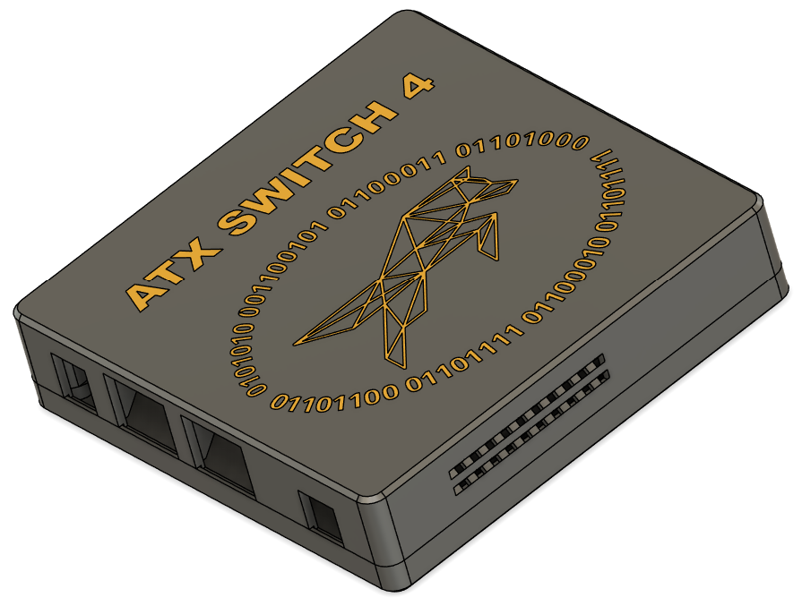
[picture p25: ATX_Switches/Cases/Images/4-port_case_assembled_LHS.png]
|  |  |

Consists of:

- Printed in PLA
- Common base
- ATX Switch 4 top
  - Configured with cut-outs for the connectors on the main board and ventilation holes (not that the unit generates much heat)
  - Uses  [M3(OD4.5) 6mm heat inserts](https://www.aliexpress.com/item/1005006042691803.html?) within the support pillars to allow for repeated opening / closing. 

Case parts are fastened together with 4x 14mm countersunk black M3 bolts.

## 8-port - (ATX SWITCH 8)

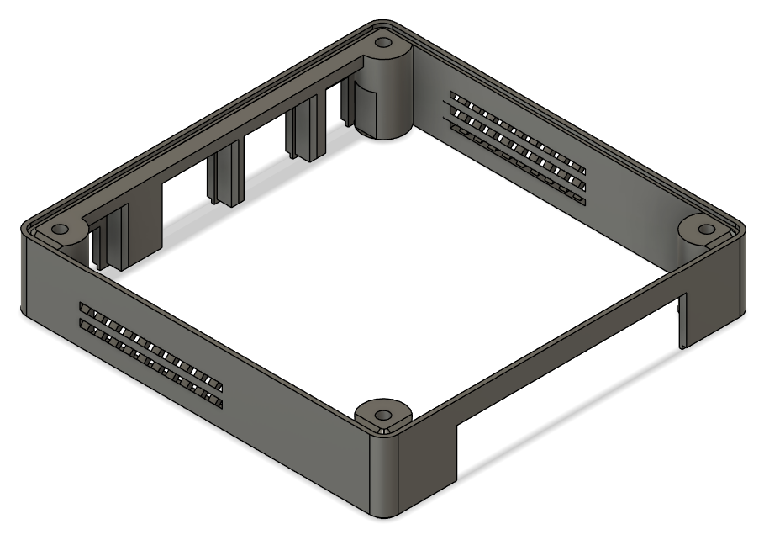
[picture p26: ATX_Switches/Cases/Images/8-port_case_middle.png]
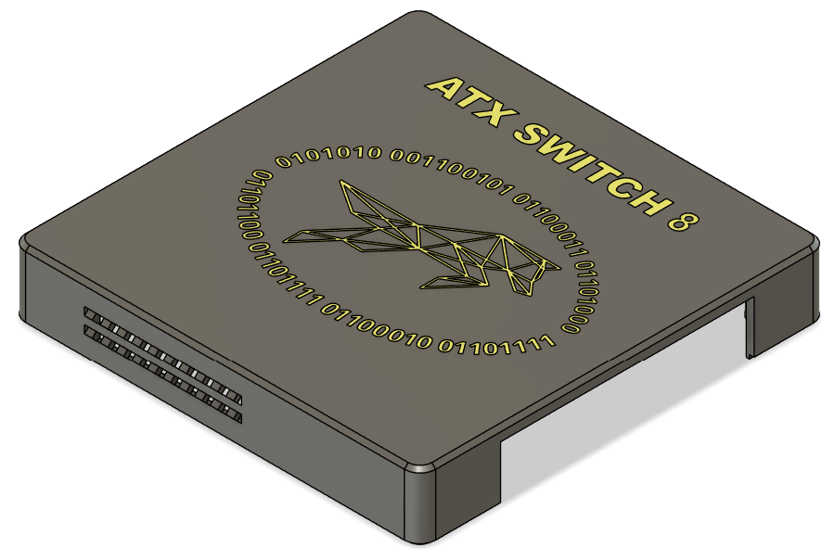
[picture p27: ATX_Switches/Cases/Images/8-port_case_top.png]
|  |  |  |
| --- | --- | --- |

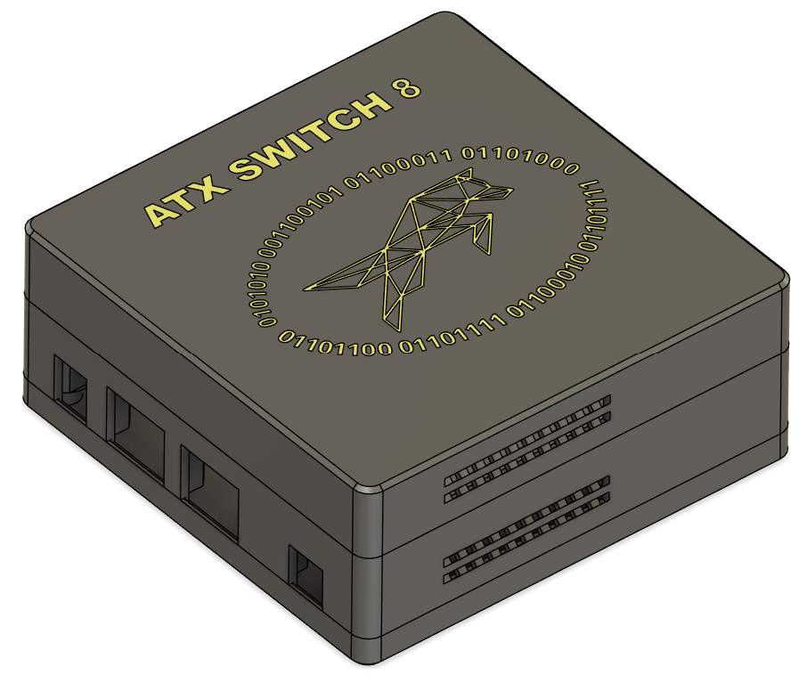
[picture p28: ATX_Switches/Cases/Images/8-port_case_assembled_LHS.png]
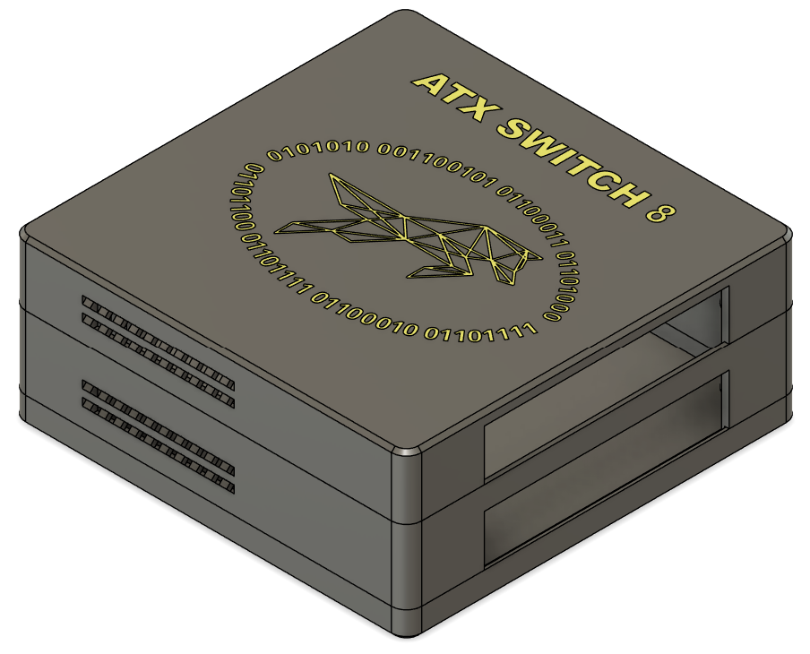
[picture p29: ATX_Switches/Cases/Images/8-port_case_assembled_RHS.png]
|  |  |
| --- | --- |

Consists of:

- Printed in PLA
- Common base
- Middle layer
  - Configured with cut-outs for the connectors on the main board and ventilation holes (not that the unit generates much heat)
- ATX Switch 8 top
  - Provides ventilation holes
  - Uses  [M3(OD4.5) 6mm heat inserts](https://www.aliexpress.com/item/1005006042691803.html?) within the support pillars to allow for repeated opening / closing.

Case parts are fastened together with 4x 35mm countersunk black M3 bolts.

>[!NOTE]
>The use of heat inserts is not compulsory but the inner diameter of the mounting hole on the pillars will probably need to be adjusted if M3 screws (or bolts) are to be used on their own.

>[!TIP]
>Case surface stability can be improved by attaching (4x) 10x2mm self adhesive rubber feet to the underside of the base in the indentations provided.

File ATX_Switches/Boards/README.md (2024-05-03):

This sub-folder contains the details on the ATX Switch [main board](./Main_board/README.md) (4-port operation), and [daughter board](./Daughter_board/README.md) (additional 4-port operation) components.

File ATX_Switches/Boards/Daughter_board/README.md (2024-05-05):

# Daughter board



This board is a mirror of the de/multiplexor, managed device isolation, and 4-port connector functionality of the Main board.

It was designed to sit above the Main board, with the same port orientation, and bridged via the 12-pin (2x6) connector. 

It is attached to the main board via 4x [M2.5 18mm brass standoffs](https://www.aliexpress.com/item/1005003320815605.html) (with associated [M2.5 6mm bolts](https://www.aliexpress.com/item/1005003294513501.html)), and is shaped to allow for the support posts in the 3D printed case. All mounting holes are M2.5 and align with the matching holes on the Main board.

The board was also designed to enable access to the jumpers on the Main board once it was attached.

As per the Main board the isolation components can be either SSRs or optocouplers.

Again sockets were used for test purposes and can be omitted from board creation.

### Daughter board presence check

The only additional functionality that this board provides is support of a daughter board presence test. This consists of the ability to use the 2nd channel on the third CD4052B to check for a high ('1') signal DB_test line when the second RJ45 port of the daughter board is selected. Basically each of the RJ45 ports on the daughter board are selected sequentially and the value returned from DB_test (via I2C) is read. All ports should read low ('0') apart from the second port, so the sequence read should be - 0,1,0,0.

In theory you don't have to check all of the ports - could just verify that port2 on daughterboard returns ‘1’, but checking that one of the others returns ‘0’ may be a useful sense check. Ensure that the selected port value is also returned for verification. 

May be worth doing multiple reads on port 2 (or the full sequence) just to ensure that you aren’t getting a floating value. i.e. 10 or 20 consecutive reads with same value consistently returned gives confidence – this only gets done during initialisation so isn’t really any particular overhead.

As mentioned in the main board description, if I2C_HDD jumper is set to enable reading of HDD_LED status via I2C then the daughter board test functionality will not work as the 2nd channel on the third CD4052B will not be enabled.

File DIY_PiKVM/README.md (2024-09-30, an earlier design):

# DIY PiKVM Section

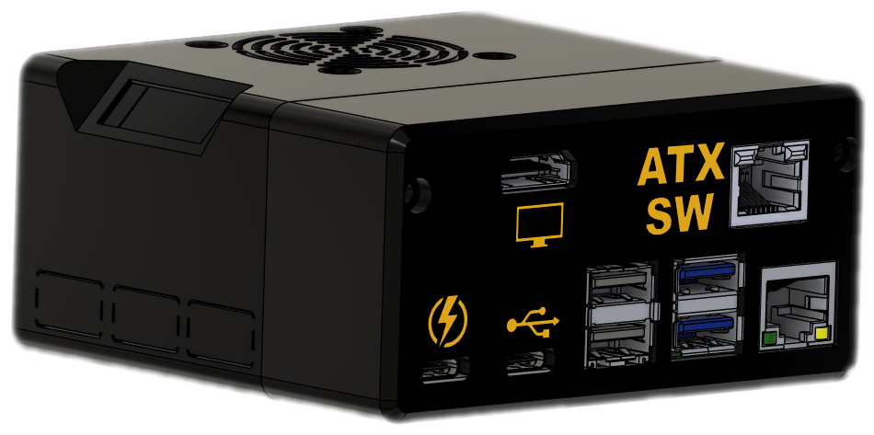
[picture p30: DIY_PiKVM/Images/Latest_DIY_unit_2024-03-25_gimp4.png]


The *DIY PiKVM for ATX Switch* consists of:

## Hardware

- [3D printed case](./Case/README.md)
- Pi4 (suitable for PiKVM)
- [Power splitter](https://www.tindie.com/products/8086net/usb-cpwr-splitter/) from 8086.com
  - Barrel jack version not required, although will fit.

- [Angled USB-C cable](https://www.startech.com/en-gb/cables/r2ccr-15c-usb-cable) connecting Power splitter to Pi4 USC-C power supply port
  - Other cables / adaptors can potentially be used but I found this item to be best for the available space / bend.

- [C790](https://geekworm.com/products/c790) to provide HDMI-CSI2 video capture 
  - FPC 15-pin cable should also be supplied 
  - (audio if required using supplied I2S cable)

- [ATX Switch connector](./ATX_Switch_connector_board_for_Pi/README.md) (RJ45 configured with GPIO connectivity for ATX Switch)
- [0.91 inch OLED screen](https://www.aliexpress.com/item/1005005281308478.html) (typically white / yellow / blue)
  - 4-pin female-to-female dupont ribbon cable

- 4x 2mm silicone cushion mat self adhesive rubber feet
- **Optional** - 40x40x10 fan (preferably PWM). Few types tested:
  - [Noctua NF-A4x10 5V PWM](https://noctua.at/en/nf-a4x10-pwm)
  - [Pi5 PWM fan](https://thepihut.com/products/4010-cooler-black-fan-for-raspberry-pi-5?variant=42684803907779)
  - [GeeekPi PWM fan](https://www.amazon.co.uk/GeeekPi-Raspberry-Adjustable-40x40x10mm-Radiator/dp/B092ZF995F?th=1)
  - There are others, but not tested.

The case construction allows for mainly tool-less assembly, however the following bolts / connectors **are** used in the build of the unit:

- 2x M3 35mm bolts for connecting the front and back of the case together.
  - I used [black hex socket head bolts](https://www.aliexpress.com/item/1005005832717344.html) (to match in with the black PLA) together with [M3(OD4.5) 6mm heat inserts](https://www.aliexpress.com/item/1005006042691803.html) in the case back to provide a good fit that can be opened / closed easily. The use of heat inserts is not compulsory but the inner diameter of the mounting hole on the back case will probably need to be adjusted if M3 screws (or bolts) are to be used on their own.
- 4x M3 15mm bolts / nuts to fasten the fan into place
  - I used [black D4(M3) screw book binding post screws](https://www.aliexpress.com/item/32789781458.html) together with rubber washers to provide a good looking finish with the Noctua NF-A4x10 5V PWM fan.
- **Optional** - depending on preference, an M2.5 brass standoff spacer (18mm) can be used in conjunction with 2x M2.5 6mm low flat screws to fasten the ATX Switch connector board to the Raspberry Pi4. This is not essential as the case construction will hold the components together, but may provide rigidity during assembly.

### Hardware Assembly

1. Install the fan in the top of the case back

2. Attach the ATX Switch connector board to the Pi 4b GPIO header

   1. If desired affix the brass standoff spacer between the GPIO header and the Pi 4b Ethernet port
   1. Do **not** affix spacer at back of Pi4 and ATXCB as this will prevent the unit sliding into the supporting slots at the rear of the case.

3. Connect one end of the 4-pin female-to-female dupont cable to the OLED pins noting which dupont wire is connected to which OLED pin. Connect the other end of the dupont cable to the OLED connector on the ATX Switch connector board (ATXCB) - the pinout should be:

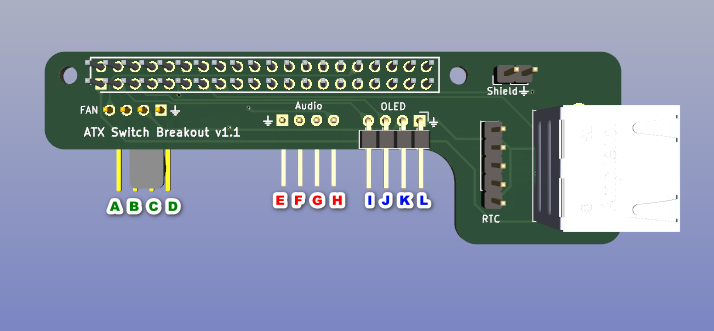
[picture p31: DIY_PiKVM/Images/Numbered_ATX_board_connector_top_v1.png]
   
Numbered_ATX_board_connector_top_v1

    | OLED Screen pins | ATXCB OLED connector       |
    | ---------------- | -------------------------- |
    | GND              | ${\textsf{\color{blue}L}}$ |
    | VCC              | ${\textsf{\color{blue}K}}$ |
    | SCL              | ${\textsf{\color{blue}J}}$ |
    | SDA              | ${\textsf{\color{blue}I}}$ |

4. Connect the straight end of the Angled USB-C cable to the single USB-C connector on the power splitter, and fit the power splitter into the case (should just slide in).

5. If audio is required then connect the dupont connectors from the cable supplied with the C790 to the relevant pins on the ATXCB. These are:

    | C790 I2S connector | Dupont connector | ATXCB connector           |
    | ------------------ | ---------------- | ------------------------- |
    | GND                | 1                | ${\textsf{\color{red}E}}$ |
    | WFS                | 2                | ${\textsf{\color{red}F}}$ |
    | SD                 | 3                | ${\textsf{\color{red}G}}$ |
    | SCK                | 4                | ${\textsf{\color{red}H}}$ |

    Connect the SH1 plug on the I2S cable to the socket on the C790. Refer to the [Geekworm wiki](https://wiki.geekworm.com/C790) for further details.

    Note - this has not been tested fully.

6. Connect the 15-pin FPC cable to the connector on the C790 (blue tag should be visible when viewing top of board).

7. Insert the C790 HDMI-to-CSI board into the slots on the inside front of the case with the HDMI connector located in the relevant (shaped) hole.

8. Place the Pi4 onto the bottom of the case back with the USB / Ethernet ports towards the front.

9. Connect the angled USB-C connector to the Power port (USB-C) to the rear left hand side of the Pi4.

10. Connect the Fan cable to the relevant header on the ATXCB

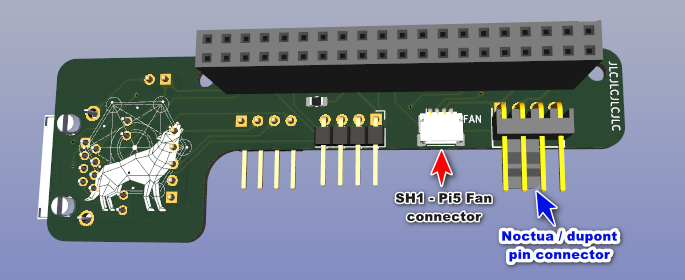
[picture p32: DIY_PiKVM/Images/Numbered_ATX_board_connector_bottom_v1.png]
    
Numbered_ATX_board_connector_bottom_v1

    1. If it is a Noctua fan then the plug is keyed which defines direction.

    2. If it is a Pi5 PWM fan then it connects to the SH1 connector, which is also directional.

    3. If a GeeekPi (or other generic) PWM fan is used then the Fans dupont wires can be connected to the same connector used by the Noctua with the following pinout:

       | GeeekPi (generic) PWM | Noctua / dupont connector   |
       | --------------------- | --------------------------- |
       | GND (Black)           | $\color{green}{\textsf{D}}$ |
       | +5V (Red)             | $\color{green}{\textsf{C}}$ |
       | PWM (Blue)            | $\color{green}{\textsf{A}}$ |

       If RPM wire is available then can try connecting this to pin $\color{green}{\textsf{B}}$, but I had issues with getting this to work reliably so ended up only configuring the **fan.ini** file to support PWM operation (which worked fine).

11. Connect the free end of the 15-pin FPC cable into the Pi4 CSI port (blue tag towards the USB connectors).

12. Slide the Pi4 and ATXCB assembly into the slots in the front of the case (the USB and RJ45 connectors should nest into the relevant cut-outs in the case front).

13. Position the OLED screen into the relevant slot on the LHS of the case back, and gently slide the front and back of the case together, ensuring that the Pi4 slides into the supporting slots in the back of the case.

     1. It will be necessary to tuck in (/ fold) the various cables during this activity in order to get everything in without causing disconnections.
     2. Make sure that the FPC cable does not come out of its socket.
     3. It may be necessary to repeat this exercise a couple of times to get everything seated correctly.

14. Fasten the front and back of the case together with the M3 35mm bolts.

15. Once the software has been installed / configured, insert the SD card into the Pi4, power-up and test.

## Software

- [PiKVM v3 box software](https://files.pikvm.org/images/)
  - The latest image tested with is **v3-hdmi-rpi4-box-20240417.img.xz** with the following additions / modifications.
- [ATX Switch related](./Scripts/README.md)
  - python scripts
  - PiKVM configuration file changes

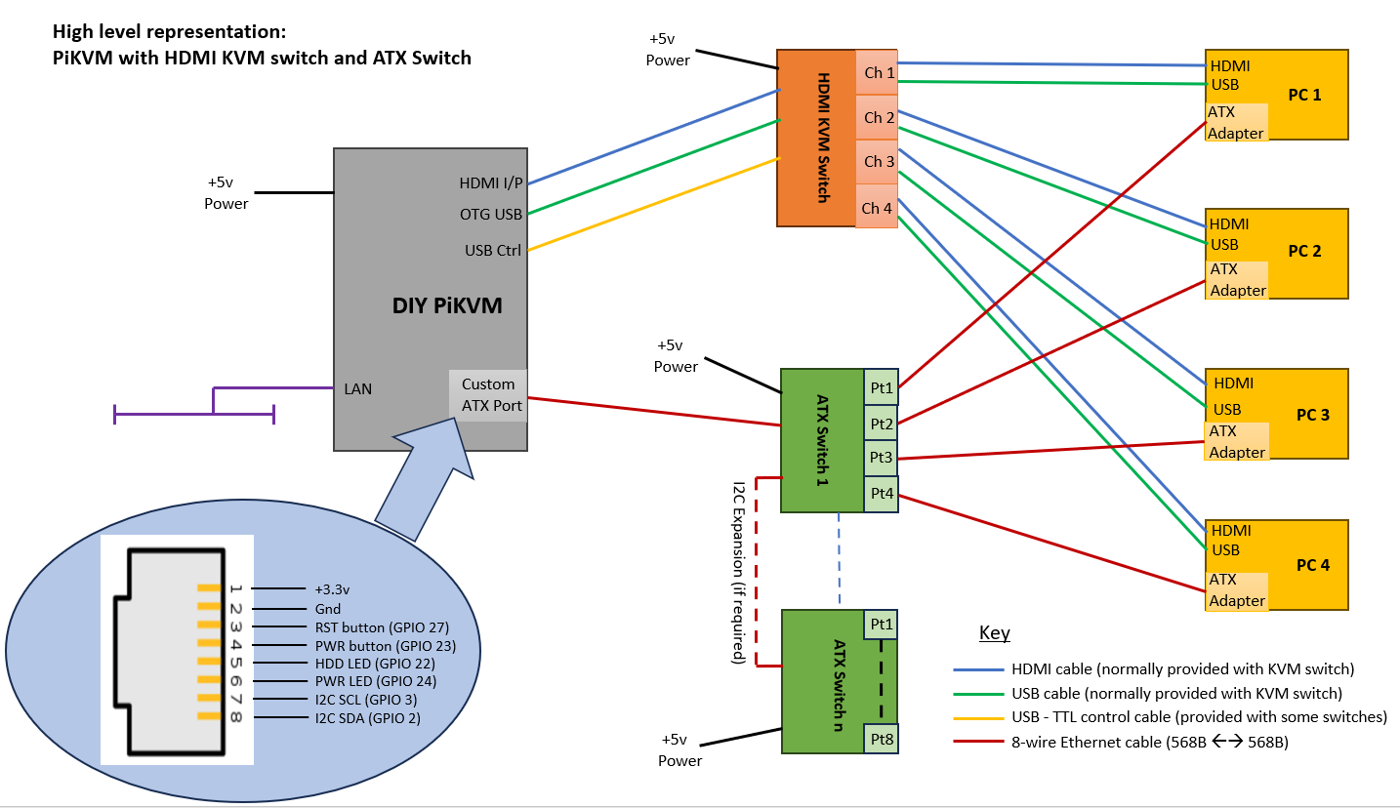
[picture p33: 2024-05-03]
Images/Typical_deployment_architecture_v1.png

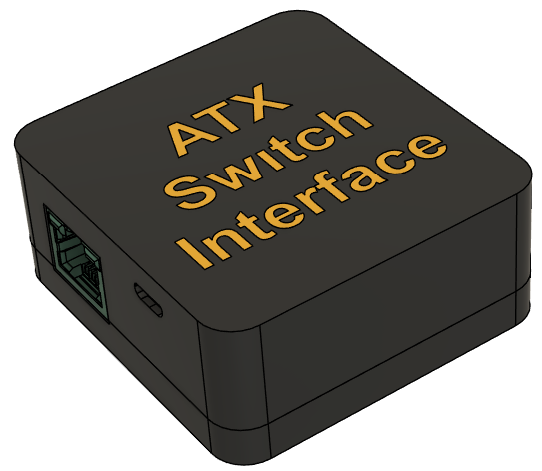
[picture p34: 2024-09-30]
Images/ATX_Switch_Interface_adaptor.png

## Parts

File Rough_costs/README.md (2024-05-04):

# Rough costs

A breakdown of the costs is provided in the [Rough_Costs PDF](./rough_costs.pdf) file.

>[!NOTE]
>**No labour costs (e.g. purchasing / soldering / construction / testing) are taken into account** - this work was undertaken on a hobby basis.

>[!TIP]
>If you have access to your own 3D printing capability then the cost of the cases will be limited to the cost of material. I use the facilities within my local Makerspace / Man Shed, so **my costs were minimal** and I could ensure the quality produced.

The cost of the cases provided is a rough figure from running the .STEP files through [Craftcloud 3D printing services](https://craftcloud3d.com/) and going with the cheapest option - I can't say what the quality of these will be!

All components were purchased for the best price available, taking account of any approaches to reducing / removing shipping costs (minimum order level, longer delivery times, etc.). The majority of the passive components, and a few of the active ones, were purchased from Aliexpress.

All prices are done on a pro-rata basis - e.g. 1-port RJ45 connectors are used in more than one item and therefore a bundle of 20x 1-port RJ45 connectors was purchased, however only a cost of 1/20th was allocated against the above costs (where an item required it). This could mean that there is spare stock for other items / projects.

Most purchases were done throughout 2023, so will probably have increased by now.

You will also need to provide power supplies / cables (Network / USB / HDMI) / etc. as required.

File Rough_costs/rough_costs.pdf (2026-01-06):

Qty Unit cost Cost
ATX Switch 4 | Total = | £36.29
Main board
PCB (assembled with all SMD components) | 1 | £8.80 | £8.80
4-port RJ45 connector | 1 | £0.97 | £0.97
1-port RJ45 connector | 2 | £0.28 | £0.56
Power connector (Barrel Jack) | 1 | £0.18 | £0.18
3-pole piano switch | 1 | £0.58 | £0.58
2x6-pin female connector | 1 | £0.18 | £0.18
MCP23008 | 1 | £1.62 | £1.62
CD4052B | 3 | £0.25 | £0.75
LTV-817-C | 20 | £0.08 | £1.60
1x3-pin vertical header (2.54mm) | 5 | £0.01 | £0.05
Jumpers | 5 | £0.08 | £0.40
Subtotal £15.69
Case
3D printed case (2-parts) | 1 | | £20.00
M3 heat inserts | 4 | £0.08 | £0.32
M3 14mm black bolts | 4 | £0.03 | £0.12
Rubber feet | 4 | £0.04 | £0.16
Subtotal £20.60
ATX Switch 8 | Total = | £48.71
Main board
costs from above | Subtotal £15.69
Daughter board
PCB (assembled with all SMD components) | 1 | £4.40 | £4.40
4-port RJ45 connector | 1 | £0.97 | £0.97
2x6-pin male connector (long) | 1 | £0.18 | £0.18
CD4052B | 3 | £0.25 | £0.75
LTV-817-C | 16 | £0.08 | £1.28
18mm hex brass spacers | 4 | £0.15 | £0.60
M2.5 6mm bolts | 4 | £0.03 | £0.12
Subtotal | £8.30
Case
3D printed case (3-parts) | 1 | | £24.00
M3 heat inserts | 4 | £0.08 | £0.32
M3 35mm black bolts - countersunk | 4 | £0.06 | £0.24
Rubber feet | 4 | £0.04 | £0.16
Subtotal £24.72
ATX Adapter board | Total = | £2.98
PCB | 1 | £0.55 | £0.55
1-port RJ45 connector | 1 | £0.28 | £0.28
2-pin 2.54mm male connector | 4 | £0.01 | £0.04
2-pin 2.54mm female connector | 4 | £0.01 | £0.04
Full height X540-T1 metal bracket | 1 | £1.00 | £1.00
PC motherboard switch extender (20cm) | 1 | £1.07 | £1.07
Subtotal | £2.98

DIY PiKVM for ATX Switch | Total = £117.10
ATX Switch connector board
PCB | 1 | £0.76 | £0.76
1-port RJ45 connector | 1 | £0.28 | £0.28
2x20 three layer heightened GPIO header | 1 | £1.32 | £1.32
KF2510 3+1P connector (for Noctua) | 1 | £0.07 | £0.07
4-pin SH1.0 connector (for Pi 5 PWM Fan) | 1 | £0.17 | £0.17
0805 4.7k SMD resistor | 1 | £0.01 | £0.01
1x5-pin vertical header | 1 | £0.01 | £0.01
1x2-pin vertical header | 1 | £0.01 | £0.01
1x4-pin horizontal header | 1 | £0.01 | £0.01
mini RTC module | 1 | £1.42 | £1.42
Subtotal | £4.06
2GB Pi4 | 1 £43.20 £43.20
C790 HDMI-CSI | 1 £22.80 £22.80
USB-C power splitter | 1 | £3.55 | £3.55
Angled USB-C cable | 1 | £6.13 | £6.13
0.91 inch OLED screen (yellow) | 1 | £1.70 | £1.70
4-pole dupont female-female 10cm | 1 | £0.33 | £0.33
Noctua NF-A4x10 5V PWM | 1 £13.95 £13.95
Subtotal £91.66
Case
3D printed case (2 parts) | 1 | | £20.00
M3 heat inserts | 2 | £0.08 | £0.16
M3 35mm black bolts - cap head | 2 | £0.07 | £0.14
Rubber feet | 4 | £0.04 | £0.16
D4(M3) 15mm post screws | 4 | £0.22 | £0.88
M3 rubber washer | 4 | £0.01 | £0.04
Subtotal £21.38
ATX Switch Interface | Total = | £24.19
ATX Switch Interface board
PCB | 1 | £0.46 | £0.46
1-port RJ45 connector | 2 | £0.28 | £0.56
2x7-pin female connector (2.54mm) | 1 | £0.14 | £0.14
2x4-pin male connnector (2.54mm) | 1 | £0.05 | £0.05
11mm hex brass spacers | 2 | £0.17 | £0.34
M2.5 6mm bolts | 4 | £0.03 | £0.12
Subtotal | £1.67
CP2112 debug board | 1 | £4.12 | £4.12
Subtotal | £4.12
Case
3D printed case (2-parts) | 1 | | £18.00
M2.5 heat inserts | 4 | £0.07 | £0.28
M2.5 12mm black bolts (countersunk) | 4 | £0.03 | £0.12
Subtotal £18.40
DIY PiKVM v2 (single ATX) | Total = £118.15
ATX connector board
PCB | 1 | £0.76 | £0.76

1-port RJ45 connector | 1 | £0.28 | £0.28
2x20 three layer heightened GPIO header | 1 | £1.32 | £1.32
KF2510 3+1P connector (for Noctua) | 1 | £0.07 | £0.07
4-pin SH1.0 connector (for Pi 5 PWM Fan) | 1 | £0.17 | £0.17
0805 4.7k SMD resistor | 1 | £0.01 | £0.01
1x5-pin vertical header | 1 | £0.01 | £0.01
1x2-pin vertical header | 1 | £0.01 | £0.01
1x4-pin horizontal header | 1 | £0.01 | £0.01
mini RTC module | 1 | £1.42 | £1.42
KAQY214 SSR | 4 | £0.54 | £2.16
Subtotal | £6.22
2GB Pi4 | 1 £43.20 £43.20
C790 HDMI-CSI | 1 £19.99 £19.99
USB-C power splitter | 1 | £4.20 | £4.20
Angled USB-C cable | 1 | £6.13 | £6.13
0.91 inch OLED screen (yellow) | 1 | £1.70 | £1.70
4-pole dupont female-female 10cm | 1 | £0.33 | £0.33
Noctua NF-A4x10 5V PWM | 1 £15.00 £15.00
Subtotal £90.55
Case
3D printed case (2 parts) | 1 | | £20.00
M3 heat inserts | 2 | £0.08 | £0.16
M3 35mm black bolts - cap head | 2 | £0.07 | £0.14
Rubber feet | 4 | £0.04 | £0.16
D4(M3) 15mm post screws | 4 | £0.22 | £0.88
M3 rubber washer | 4 | £0.01 | £0.04
Subtotal £21.38

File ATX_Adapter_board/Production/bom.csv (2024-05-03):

Designator | Footprint | Quantity | Value | LCSC Part #
H1, H2 | MountingHole_3.2mm_M3_Pad | 2 | MountingHole_Pad
J1 | RJHSE5381 | 1 | RJHSE-5381 |  | https://www.aliexpress.com/item/32728838902.html
J10, J4, J6, J8 | PinSocket_1x02_P2.54mm_Vertical | 4 | Conn_01x02
J3, J5, J7, J9 | PinHeader_1x02_P2.54mm_Vertical | 4 | Conn_01x02

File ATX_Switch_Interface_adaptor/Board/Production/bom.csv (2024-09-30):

Designator | Footprint | Quantity | Value | LCSC Part #
J1, J2 | RJHSE5381 | 2 | RJHSE-5381
J3 | PinHeader_2x04_P2.54mm_Vertical | 1 | Conn_02x04_Top_Bottom
U1 | CP2112 Debug Board | 1 | ~

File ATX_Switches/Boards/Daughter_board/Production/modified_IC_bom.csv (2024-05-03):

Designator | Footprint | Quantity | Value | Do Not Populate | LCSC Part # | Potential Source
C1, C2, C3 | 603 | 3 | 100nF |  | C14663
H2, H3, H5, H6 | MountingHole_2.7mm_M2.5_DIN965_Pad_TopBottom | 4 | MountingHole_Pad
J1 | PinSocket_2x06_P2.54mm_Vertical | 1 | Conn_02x06_Odd_Even | DNP | C2935986
J2 | AMPHENOL_RJHSE-5381-04 | 1 | RJHSE-5381-04 | DNP |  | https://www.aliexpress.com/item/32730855182.html
R10, R2, R3, R4, R5, R6, R7, R8, R9 | 603 | 8 | 4.7k |  | C23162
R11, R12, R13, R14, R15, R16, R17, R18, R19, R20, R21, R22, R23, R24, R25, R26, R27 | 603 | 17 | 390 |  | C23151
U1, U2, U3 | DIP-16_W7.62mm_Socket_LongPads | 3 | CD4052B | DNP | C507162
U10, U11, U12, U13, U14, U15, U16, U17, U18, U19, U4, U5, U6, U7, U8, U9 | DIP-4_W7.62mm_Socket_LongPads | 16 | LTV-817 | DNP | C109225

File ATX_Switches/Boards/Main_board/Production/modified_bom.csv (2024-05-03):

Designator | Footprint | Quantity | Value | LCSC Part # | Do Not Place | Potential Source | Notes
C1, C11 | 603 | 2 | 1uF | C15849
C10, C2, C4, C5, C6, C7, C8, C9 | 603 | 8 | 100nF | C14663
H1, H2, H3, H4, H5, H6, H7, H8 | MountingHole_2.7mm_M2.5_DIN965_Pad_TopBottom | 8 | MountingHole_Pad
J1, J2 | RJHSE5381 | 2 | RJHSE-5381 |  | DNP | https://www.aliexpress.com/item/32728838902.html
J10 | PinHeader_2x03_P2.54mm_Vertical | 1 | Conn_02x03_Odd_Even | C5116479 | DNP |  | Optional - not required if piano switch used
J11, J5, J7, J8, J9 | PinHeader_1x03_P2.54mm_Vertical | 5 | Conn_01x03 | C429954 | DNP
J3 | PinSocket_2x06_P2.54mm_Vertical | 1 | Conn_02x06_Odd_Even | C2935986 | DNP | https://www.aliexpress.com/item/32851433725.html | Need 6-pin double row sockets (12-pin total)
J4 | BarrelJack_Horizontal_163-179PH-EX | 1 | 163-179PH-EX | C194407 | DNP | https://www.aliexpress.com/item/4001206395694.html
J6 | AMPHENOL_RJHSE-5381-04 | 1 | RJHSE-5381-04 |  | DNP | https://www.aliexpress.com/item/32730855182.html
R1, R15, R16, R17, R18, R19, R2, R20, R21, R22, R3, R31, R32, R33, R34, R39, R4, R40, R5, R6, R7, R8, R9 | 603 | 23 | 390 | C23151
R10, R11, R12, R23, R24, R25, R26, R27, R28, R29, R30, R35, R36, R41, R42 | 603 | 15 | 4.7k | C23162
R13, R14, R37, R38 | 603 | 4 | 10K | C25804
S2 | NDP03TV | 1 | NDP-03T-V | C126880 | DNP | https://www.aliexpress.com/item/32963042282.html | Need 3-pole piano switch
U1, U2, U3 | DIP-16_W7.62mm_Socket_LongPads | 3 | CD4052B | C507162 | DNP
U10, U11, U12, U13, U14, U15, U16, U17, U18, U20, U21, U22, U23, U24, U25, U26, U5, U7, U8, U9 | DIP-4_W7.62mm_Socket_LongPads | 20 | LTV-817 | C109225 | DNP
U19 | TSSOP-8_3x3mm_P0.65mm | 1 | 74LVC2G32DP,125 | C548635
U27 | SOIC-8_3.9x4.9mm_P1.27mm | 1 | ISO1540 | C179739
U28 | SOT-89-3_Handsoldering | 1 | TPMCP1702T-3302E/MB | C3040635
U4 | DIP-18_W7.62mm_Socket_LongPads | 1 | MCP23008-xP |  | DNP | https://www.mouser.co.uk/ProductDetail/Microchip-Technology/MCP23008-E-P?qs=8FMarzwez060sofcCmNWdQ%3D%3D
U6 | SOT-23-6_Handsoldering | 1 | SN74LVC2G04DBVR | C10428

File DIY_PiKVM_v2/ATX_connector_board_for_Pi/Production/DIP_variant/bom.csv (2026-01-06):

Designator | Footprint | Quantity | Value | LCSC Part # | Do Not Place | Potential source
J2 | RJHSE5381 | 1 | RJHSE-5381 |  | DNP | https://www.aliexpress.com/item/32728838902.html
J3 | RHDR40W64P254_2X20_5130X500X1625P | 1 | PRT-16763 |  | DNP | https://www.aliexpress.com/item/1005005366790021.html
J4 | PinHeader_1x05_P2.54mm_Vertical | 1 | Conn_01x05_Pin |  | DNP
J5, J6 | PinHeader_1x04_P2.54mm_Horizontal | 2 | Conn_01x04_Pin |  | DNP
J7 | PinHeader_1x02_P2.54mm_Vertical | 1 | Conn_01x02_Pin |  | DNP
J8 | HDRRA4W64P0X254_1X4_1001X318X635P | 1 | 171857-0004 |  | DNP | https://www.aliexpress.com/item/1005002905132620.html
J9 | JST_SH_SM04B-SRSS-TB_1x04-1MP_P1.00mm_Horizontal | 1 | Conn_01x04_MountingPin | C160404 | DNP
R1, R6, R7 | 0805 | 3 | 4.7K | C17673 | DNP
R2, R3, R4, R5 | 0805 | 4 | 390 | C17655 | DNP
U1, U2, U3, U4 | DIP-4_W7.62mm | 4 | KAQY214 | C136415 | DNP

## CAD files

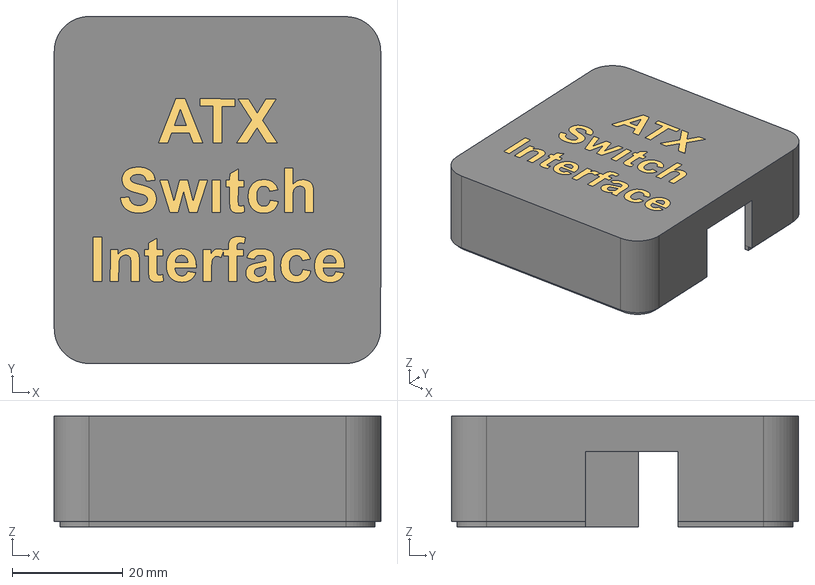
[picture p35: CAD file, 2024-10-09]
ATX_Switch_Interface_adaptor/Case/Production/ATX SW Interface box Top v1.step
58.9 x 62.6 x 20.0 mm
Box top v1
Top text

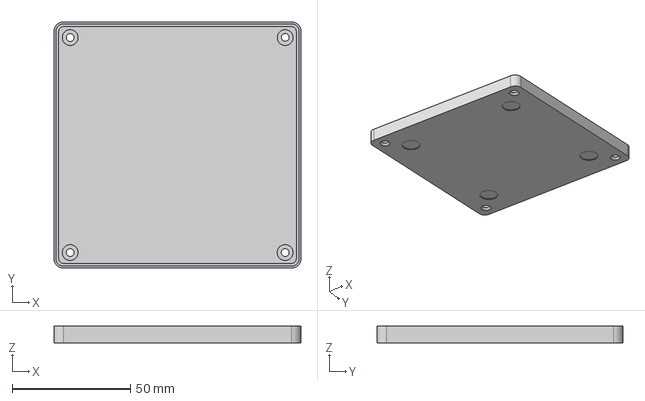
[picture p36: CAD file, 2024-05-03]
ATX_Switches/Cases/Production/ATX Switch bottom.step
104.5 x 104.1 x 7.10 mm

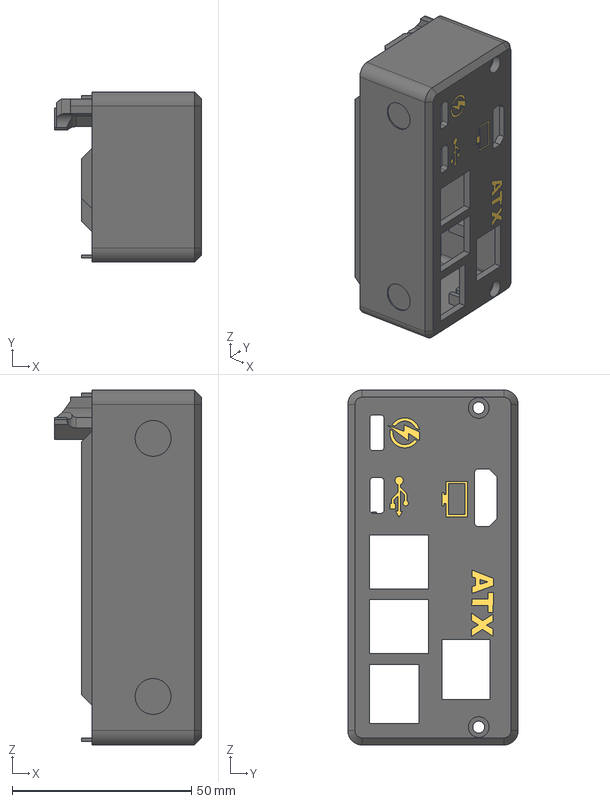
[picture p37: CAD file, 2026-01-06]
DIY_PiKVM_v2/Case/Production/DIY_PiKVM_v2_ATX_front.step
41.0 x 47.5 x 99.0 mm
Front v1
Label

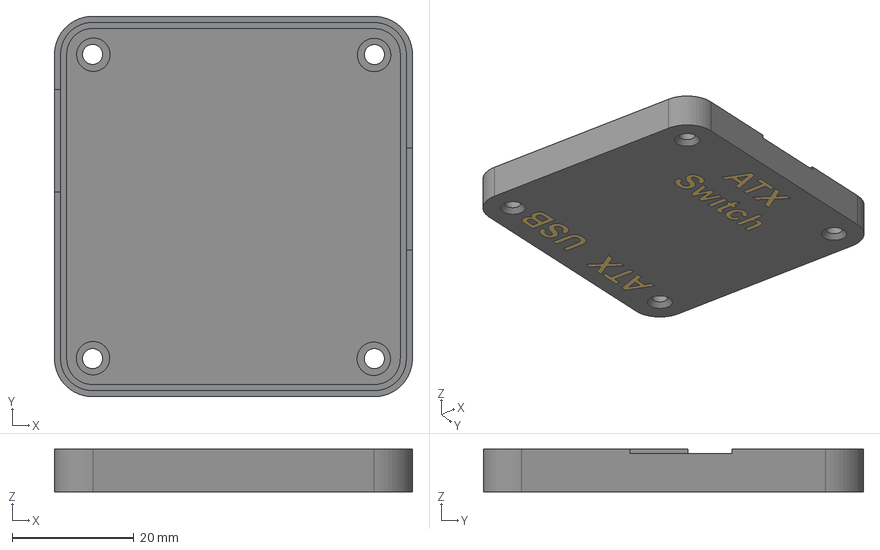
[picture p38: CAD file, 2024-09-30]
ATX_Switch_Interface_adaptor/Case/Production/ATX SW If box base v1.step
58.9 x 62.6 x 7.00 mm
Box base v2
Bottom text

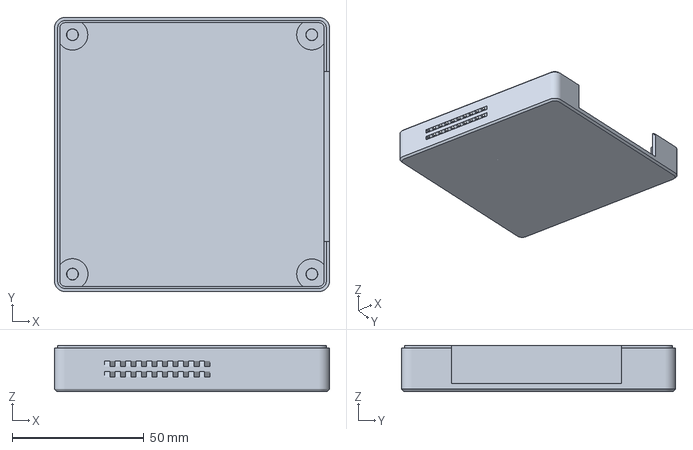
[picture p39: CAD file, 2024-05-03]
ATX_Switches/Cases/Production/ATX Switch 8-port top.3mf
104.5 x 104.1 x 17.6 mm

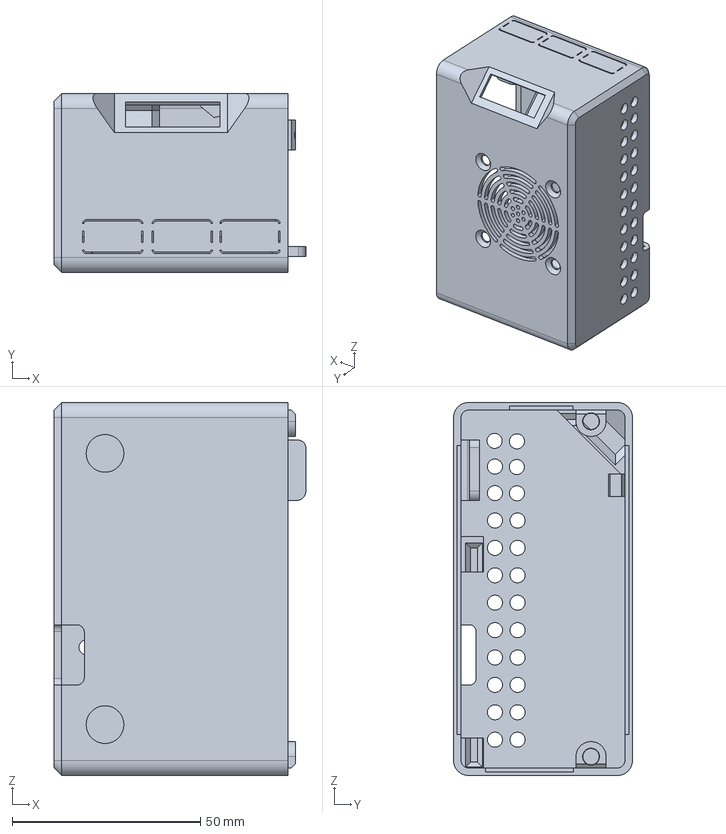
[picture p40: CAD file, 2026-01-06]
DIY_PiKVM_v2/Case/Production/DIY_PiKVM_v2_ATX_back.step
66.8 x 47.5 x 99.0 mm

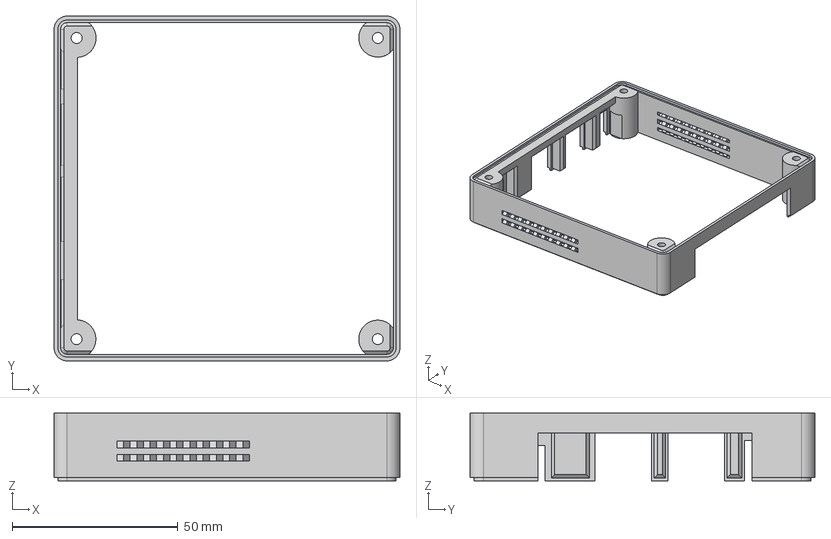
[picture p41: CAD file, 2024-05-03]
ATX_Switches/Cases/Production/ATX Switch 8-port middle.step
104.5 x 104.1 x 20.5 mm

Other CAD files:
ATX_Switches/Cases/Production/ATX Switch 4-port top - 2 colour.3mf
DIY_PiKVM/Case/Production/DIY_PiKVM_ATXSW_v1_back.step
DIY_PiKVM/Case/Production/DIY_PiKVM_ATXSW_v1_front.step
ATX_Switch_Interface_adaptor/Case/Production/ATX SW If box base v1.3mf
ATX_Switch_Interface_adaptor/Case/Production/ATX SW Interface box Top v1.3mf
ATX_Switches/Cases/Production/ATX Switch 8-port middle.3mf
ATX_Switches/Cases/Production/ATX Switch bottom.3mf

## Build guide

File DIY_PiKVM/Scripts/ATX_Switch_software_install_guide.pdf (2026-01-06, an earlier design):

### Steps to install ATX software environment from scratch

NOTE – ATX Switch operation requires a custom ATX interface connector which therefore necessitates a DIY PiKVM hardware build – standard PiKVM units (v3 / v4) will not support this operation without re-purposing the ATX interface.

1. Install new base PiKVM image to SD card – use latest v3 box image as will be installing into own DIY box which has OLED / FAN / RTC incorporated. If not using this case / setup then use v2 image for HDMI-CSI bridge or HDMI-USB dongle – whichever is your setup / preference.
2. Insert SD card into Pi 4b and boot. This assumes that the unit has been assembled already (see separate instructions).
3. Once the system has completed its first boot routine, open TTY session and login to unit – IP address should be displayed on OLED screen, but, if necessary, determine the assigned DHCP address from your network / router.
4. The following steps are not strictly necessary for ATX support but might as well do them first (this assumes that you are using the DIY build that includes v3 functional components – if not then can skip them):
a. Place file system into read/write mode by executing command - rw
b. [Optional now] The latest V3 Box release appears to have fixed the fan operation, but if have issues, or want to set minimum speed lower then update /etc/kvmd/fan.ini to have following values:

[main]
pwm_pin = 12

[speed]
idle = 20
low = 20

[server]
unix = /run/kvmd/fan.sock
unix_rm = 1
unix_mode = 666
c. Update /boot/config.txt to change Clock dtoverlay to be dtoverlay=i2c-rtc,ds1307
d. Disable the watchdog service - systemctl disable --now kvmd-watchdog
e. Rotate the OLED display (if required – mine did!):
i. Use the following code snippet provided on Discord by ‘The Adam Bomb’ on 06/06/2023 20:10 ->

cat << EOF > /usr/lib/systemd/system/kvmd-oled-rotate.service
[Unit]
Description=PiKVM - A small OLED daemon After=systemd-modules-load.service ConditionPathExists=/dev/i2c-1

[Service]
Type=simple
Restart=always
RestartSec=3
ExecStartPre=/usr/bin/kvmd-oled --interval=3 --rotate=2 --clear-on-exit --image=/usr/share/kvmd-oled/hello.ppm ExecStart=/usr/bin/kvmd-oled --rotate=2 --clear-on-exit TimeoutStopSec=3

[Install]
WantedBy=multi-user.target
EOF
systemctl daemon-reload
systemctl disable kvmd-oled.service systemctl enable kvmd-oled-rotate.service systemctl start kvmd-oled-rotate.service

[Note – I had to modify his script to change the ‘rotate’ values to 2 as shown above]

5. Make sure that I2C group is present, and if not then add it:
a. cat /etc/group
b. groupadd i2c
6. Make sure that ‘kvmd’ user is part of i2c group - gpasswd -a kvmd i2c
7. Install i2c-tools by following the steps at https://arcanesciencelab.wordpress.com/2014/02/02/bringing-up-i2c-on-the-raspberry-pi-with-arch-linux/ (https://arcanesciencelab.wordpress.com/2014/02/02/bringing-up-i2c-on-the-raspberry-pi-with-arch-linux/)
8. Reboot the system and ensure that changes have taken effect:
a. Fan should run at reduced speed
b. timedatectl should show that RTC time is operational and matches Local / Universal time. Note – may need to do additional configuration if need to incorporate RTC in local timezone.
c. I2cdetect -y 1 should show addresses of installed devices: hex addresses of any installed ATX switches (usually starting at 0x20); 0x3c for OLED screen; and UU at address 0x68 for the RTC.
9. Ensure that the PiKVM operates correctly (with KVM switch if present) before starting ATX

### environment installation. There is no point in trying to configure / debug ATX Switch operations if the basic PiKVM operation (including any KVM switch) is not working as it should!!

10. Once the PiKVM system is operating correctly then continue with following steps:
11. Switch filesystem back to read/write mode for now - rw
12. Create directory /etc/atx_switch with 755 permissions. This directory will contain the majority of the ATX environment scripts and initialisation / mapping YAML files (as necessary – dependent upon build).
13. The scripts that will be placed here will depend upon the system configuration and how the environment is to be presented in the PiKVM WebUI. For the purpose of this exercise, we will assume that there is one 4-port ATX switch in the environment (located at the first I2C address – 0x20) and that selection of the active port will be performed via buttons in the ‘Source’ menu tab of the WebUI, with active indication being shown via associated LED symbols.
14. To enable switching between ATX ports from the WebUI we need to include the following scripts in the /etc/atx_switch directory (ensure that they all have 755 permissions):
a. atx_change_port.py – main functional operations
b. selectx.py – where ‘x’ is the number of the ATX port assigned within your environment. In the above case this will involve: select1.py; select2.py; select3.py and select4.py. These scripts basically call atx_change_port.py with a mapped ATX switch address and port number. The scripts themselves are called from the PiKVM

‘cmd’ api as defined in the override.yaml file. Additional selectx.py scripts and associated override.yaml entries will be required for more ports / switches.
c. test_port_led.py – verifies whether a particular port is currently selected from the information held in the atx_operational.yaml file (see later).
d. port_test_x.py - where ‘x’ is the number of the ATX port assigned within your environment. Again, in the above case this will involve: port_test_1.py; port_test_2.py; port_test_3.py and port_test_4.py. These scripts basically call test_port_led.py with a mapped ATX switch address and port number. The scripts themselves are called from the PiKVM ‘cmdret’ api as defined in the override.yaml file. Additional port_test_x.py scripts and associated override.yaml entries will be required for more ports / switches.
15. Create the atx_switch_initialisation.yaml file for the system and include in the /etc/atx_switch directory. The initialisation YAML file provides configuration information on any ATX switches that are connected into the system – the I2C bus ID; how many switches present; and for each switch: the i2c address (in hex format); number of ports; how ATX operations are to be performed; whether to test for a daughterboard; and whether to run a port select test (effectively polling through each port on switch to get visual indication that it works). A debug flag can also be set which logs more detailed information during startup.
a. Note (1) – the ATX operations setting is for software usage and is dependent upon the physical settings of the jumpers on the ATX Switch main board. e.g. the atx_ops flag can be set to i2c but if the jumpers are set to RJ (buffered output from ATX connector) then PiKVM operations will still be performed using the standard GPIO mechanism.
b. Note (2) – the i2c approach to performing ATX operations is not implemented as yet! So should only use GPIO operations for now.
16. Place the initialise_atx_switches script (no .py extension) into /bin with 755 permissions.
17. Place initialise_atx_switches.service file into /usr/lib/systemd/system
18. Enable the service for startup – systemctl enable initialise_atx_switches.service
19. Create the override.yaml file for the system configuration (and user requirements for presentation / operation within the WebUI). Place this file into /etc/kvmd
a. The sample override.yaml file provided is configured to work with a single 4-port ATX Switch and an XH_HK4401 KVM switch – one of the generic devices from Aliexpress e.g. https://docs.pikvm.org/xh_hk4401/

Although I used the BLI Store version as it incorporated the USB-TTL cable required to enable programmatic switching from the Raspberry Pi (and they provide support). https://www.aliexpress.com/item/1005005149590635.html?pdp_npi=4%40dis%21G BP%21%EF%BF%A146.48%21%EF%BF%A146.48%21%21%21%21%21%40210384b21 7045198480158768e64a1%2112000031866592220%21sh%21UK%214412103182% 21&spm=a2g0o.store_pc_allItems_or_groupList.new_all_items_2007614540057.10 05005149590635 (https://www.aliexpress.com/item/1005005149590635.html)

b. The sample file presents in the PiKVM WebUI similar to:


The ‘Select’ buttons allow choice between the 4x KVM ports whose selection status is shown via the ‘Input x’ LED representations. The ATX switch ports are selected via the ‘ATXx’ buttons with selection indicated by the adjacent LED representation.

c. The override.yaml file indicates the PiKVM API commands being used and the associated scripts (with relevant path). The associated ATX switch address and port number being specified in the defined scripts. Need to change values there to match system configuration.
i. A sample override.yaml file has been provided (override_without_kvm_mapping.yaml). I you want to use this then copy it to /etc/kvmd and rename it to override.yaml. Note – this assumes that a XH_HK4401 KVM Switch is present (see below).
d. Note (1) – at this stage there is no direct integration between the KVM switch selection and the associated ATX port. Both have to be chosen manually. This can be beneficial in more complex scenarios where KVM switches are chained, or integration is not supported.
e. Note (2) – integration has only been performed with XH_HK4401 KVM Switch (as that is the device I have). If integration with other switches (e.g. ezcoo and tesmart) is required then someone with these devices will need to do the work. I assume that the approach used for the XH_HK4401 should be able to be re-used but am unable to confirm / test!
f. Note (3) – without integration the KVM switch may select the last used port during startup (the XH_HK4401 does) but the ATX switch will initialise with no port selected – so the user will need to select this as required.
20. Reboot the Pi controller
21. If everything has worked correctly then should be able to login to the PiKVM WebUI at the IP address of the DIY PiKVM unit. Can then view ATX switch port status, and switch between them from the GUI with the relevant LED representation being illuminated (physical operation can be confirmed via LED on associated port on ATX Switch).

Note – this assumes that the physical environment has all been configured and connected correctly:

a) DIY PiKVM ATX port connected to ATX Switch input;
b) pass-thru connections to other ATX Switches (if installed);
c) power to ATX switches;
d) ATX cables connected from ATX Switch outputs to the ATX adapter board on associated target PCs / servers;
e) ATX adapter boards connected to ATX motherboard headers for Power switch / Reset switch / HDD LED / Power LED;
f) ATX Adapter boards connected to PC / server case harness (if required) for above functions;
g) jumpers on ATX switches configured as required for proposed system operation (assume everything via GPIO for now);
h) address of ATX Switch(es) configured via associated unit rocker switch.
22. ATX operations / status on target device should now be available via the ATX menu in the WebUI.
23. If unable to login to WebUI, or ATX operations do not work as expected, then will need to debug the PiKVM environment.
a. Login to DIY PiKVM unit via TTY and review journalctl messages for errors.

i. journalctl -t ATX will show any messages that have been logged for the ATX Switch environment specifically e.g.

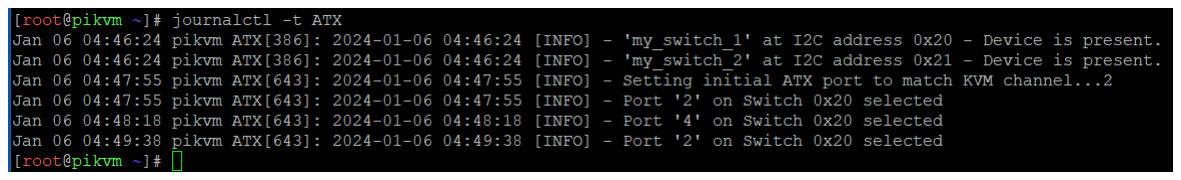
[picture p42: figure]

ii. journalctl and journalctl -fu kvmd can be used to look through the various steps that the PiKVM system goes through to startup / operate. Any errors / problems during startup (or operation) should be flagged here – typically issues with the ATX Switch environment relate to permissions issues or scripts not being present in correct place. However, they could be physical if environment not connected / powered correctly.
iii. I2cdetect -y <i2c_bus_id> can be used to ensure that the DIY PiKVM unit can see the configured ATX switches. Default for Pi4 is I2cdetect -y 1
iv. Other Linux / PiKVM API utilities can be used for more detailed debugging if required: i2cset /i2cget; https://docs.pikvm.org/api/ ; potentially https://www.acmesystems.it/gpiod (although in this case you cannot directly address the GPIO pins reserved by PiKVM, but info commands do work).
v. If necessary, the debug flag can be set in the atx_switch_initialisation.yaml file (which will provide further debug data during startup) and the system rebooted.
b. Fix any determined configuration issues and restart system.

Integration with XH-HK4401 HDMI KVM Switch

24. Create atx_kvm_mapping.yaml file and place in /etc/atx_switch
a. This mapping file consists of key pairs that map HDMI KVM Switch ‘channel’ numbers to an associated ATX Switch port (that consists of a switch address and port number).
25. Place the change_atx_from_kvm.py script into /etc/atx_switch with 755 permissions.
26. Place the atx_xh_hk4401.py PiKVM device driver into /usr/lib/python3.11/site-packages/kvmd/plugins/ugpio
27. Modify the override.yaml file to change the driver type for the HDMI KVM Switch to atx_xh_hk4401 – if desired can also change name of driver to atxhk: or alternative (although I just left it as hk:)
a. Again a sample override.yaml file has been provided (override_with_kvm_mapping.yaml). As above, copy this to /etc/kvmd and rename to override.yaml if desired.
28. Reboot the system and login to the WebUI – the ATX port associated with the previously chosen HDMI KVM channel should be selected (highlighted)
29. Switching the HDMI KVM switch to another channel, via the WebUI, will also switch the ATX selection to the associated ATX Switch port.
30. Debug if necessary.

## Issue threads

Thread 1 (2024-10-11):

Buy it somewhere

flakef, 2024-10-11:
That's a fantastic thing for pikvm4plus! Is it possible to buy ATX_Switch and ATX Switch Interface adaptors already assembled?

techlobo, 2024-10-12:
I am afraid not.

I did this for interest / fun, not to run a small business with the associated procurement, manufacturing / testing, packaging / distribution, and support hassles - all of which would have made the price of the products substantially more. This was one of the reasons for making this Open Source.

The products are fairy easy to make though provided you have basic soldering skills, as most of the components are Through Hole (TH). I had the PCB's made by JLCPCB and used their PCBA service to solder the surface mount components prior to delivery. It would probably be possible to get them to also solder the majority of the TH components, but it is likely that you would still need to solder some of the connector components yourself.

Closed 2024-10-12.

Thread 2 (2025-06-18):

PCB Schematics

Solo0101, 2025-06-18:
Can you please add the PCB schematics(files) for all the custom boards in your documentation and some recomandations for vendors from where you ordered these PCBs, that offered you this price?

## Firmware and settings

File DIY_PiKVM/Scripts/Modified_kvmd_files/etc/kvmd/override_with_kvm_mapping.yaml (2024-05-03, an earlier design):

kvmd:
    gpio:
        drivers:
            port1:
                type: cmd
                cmd: [/etc/atx_switch/select1.py]
            port2:
                type: cmd
                cmd: [/etc/atx_switch/select2.py]
            port3:
                type: cmd
                cmd: [/etc/atx_switch/select3.py]
            port4:
                type: cmd
                cmd: [/etc/atx_switch/select4.py]
            p1_led:
                type: cmdret
                cmd: [/etc/atx_switch/port_test_1.py]
            p2_led:
                type: cmdret
                cmd: [/etc/atx_switch/port_test_2.py]
            p3_led:
                type: cmdret
                cmd: [/etc/atx_switch/port_test_3.py]
            p4_led:
                type: cmdret
                cmd: [/etc/atx_switch/port_test_4.py]
            hk:
                type: atx_xh_hk4401
                device: /dev/ttyUSB0
        scheme:
            port1:
                driver: port1
                pin: 0
                mode: output
                switch: false
            port2:
                driver: port2
                pin: 1
                mode: output
                switch: false
            port3:
                driver: port3
                pin: 2
                mode: output
                switch: false
            port4:
                driver: port4
                pin: 3
                mode: output
                switch: false
            prt1_led:
                driver: p1_led
                pin: 0
                mode: input
            prt2_led:
                driver: p2_led
                pin: 1
                mode: input
            prt3_led:
                driver: p3_led
                pin: 2
                mode: input
            prt4_led:
                driver: p4_led
                pin: 3
                mode: input
            ch0_led:
                driver: hk
                pin: 0
                mode: input
            ch1_led:
                driver: hk
                pin: 1
                mode: input
            ch2_led:
                driver: hk
                pin: 2
                mode: input
            ch3_led:
                driver: hk
                pin: 3
                mode: input
            ch0_button:
                driver: hk
                pin: 0
                mode: output
                switch: false
            ch1_button:
                driver: hk
                pin: 1
                mode: output
                switch: false
            ch2_button:
                driver: hk
                pin: 2
                mode: output
                switch: false
            ch3_button:
                driver: hk
                pin: 3
                mode: output
                switch: false
        view:
            header:
                title: Source
            table:
                - []
                - ["#Input 1", ch0_led, "ch0_button|Select", "port1|ATX1", prt1_led]
                - []
                - ["#Input 2", ch1_led, "ch1_button|Select", "port2|ATX2", prt2_led]
                - []
                - ["#Input 3", ch2_led, "ch2_button|Select", "port3|ATX3", prt3_led]
                - []
                - ["#Input 4", ch3_led, "ch3_button|Select", "port4|ATX4", prt4_led]
                - []

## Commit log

2024-05-03 Initial setup of Github structure
    First load of ATX Switch information
    [ATX Switch 4-port top - 2 colour.3mf, ATX Switch 8-port middle.3mf, ATX Switch 8-port middle.step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]
2024-05-04 Move files to correct incorrect directory name
    [bom.csv, designators.csv, positions.csv]
2024-09-25 Updated to enable selection of I2C BUS ID to support other I2C controllers e.g. CP2112
    The original code was configured to use the BUS ID of the onboard Pi4 controller (bus_id = 1) that is used for DIY builds of PiKVM - and I suspect also for the purchased v3 and v4 variants.
    In order to enable these v3 / v4 variants to be used (without physical modification) with the ATX Switch it is necessary to provide an external I2C controller capability that can use existing interfa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
    However the BUS ID allocated by the controller differs from the internal int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
2024-09-25 Update atx_switch_initialisation.yaml
    Set i2c_bus_id to 1 to match default internal bus used by Pi4
2024-09-30 Added ATX Switch Interface capability
    Updated repository to include information on the ATX Switch Interface adaptor - how it is built / installed.
2024-09-30 Include production data for ATX Switch Interface
    Add omitted production data for ATX Switch Interface adaptor
    [ATX SW If box base v1.3mf, ATX SW If box base v1.step, ATX SW Interface box Top v1.3mf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]
2024-10-09 Increase size of micro USB aperture
    [ATX SW Interface box Top v1.3mf, ATX SW Interface box Top v1.step]
2024-10-09 Added picture of physical board
2025-01-06 Update README.md
    Clarified that v2 units can also use the ATX Switch interface
2026-01-06 Change of working directory for atx_operational.yaml
    The working directory for atx_operational.yaml was changed from /var/tmp/atx_switch to /run/atx_switch to cater for an issue where the file (and directory) was removed during a period of inactivity - resulting in the ATX Switch functionality failing when returned to. The use of /run will ensure that the directory/file is only removed on reboot, and the initialise_atx_switches module will then re-instate this during startup as required.
    [atx_change_port.py, test_port_led.py]
2026-01-06 Updated to account for i2c_bus_id being incorporated into atx_switch_initialisation.yaml
    The I2C Bus ID was included into the atx_switch_initialisation.yaml file, and changes made to the initialise_atx_switches module to cater for using different I2C access devices (introduced as part of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
2026-01-06 Updated case production files to .step to enable labels to be seen
    [DIY_PiKVM_ATXSW_v1_Back.stl, DIY_PiKVM_ATXSW_v1_Front.stl, DIY_PiKVM_ATXSW_v1_back.step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]
2026-01-06 Update to repository to include DIY PiKVM v2 (single ATX) device
    This modification was made some time ago to enable a basic v2 PiKVM to be created using the majority of the components that were used for the DIY PiKVM to support ATX Switch. The main change is the p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
    [DIY_PiKVM_v2_ATX_back.step, DIY_PiKVM_v2_ATX_front.step, bom.csv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]
2026-10-27 Late update to cater for new revision of Main board PCB
    I made a basic change to the Main board PCB to tune I2C comms, but in the process changed back to 2-layer board for cost.
